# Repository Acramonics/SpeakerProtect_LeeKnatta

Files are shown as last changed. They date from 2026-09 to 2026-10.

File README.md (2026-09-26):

Speaker protect circuit from Lee Knatta
https://www.diyaudio.com/community/threads/improved-speaker-protection-circuit.302384/page-6

### PSU:

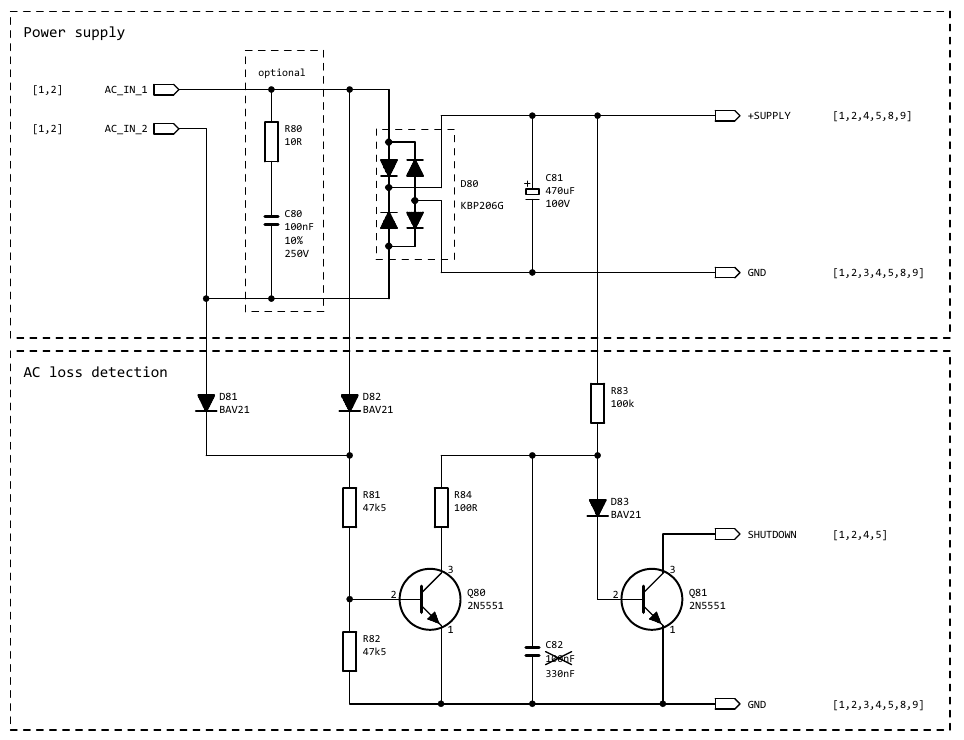
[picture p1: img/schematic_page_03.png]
PSU schematic


The power supply is just a full bridge rectifier with storage capacitor. The capacitor C81 should be large and able to withstand the voltage.
The AC loss detection uses half bridge rectifier D81 and D82 to make Q80 conduct and prevent C82 from charging up.
Once the AC fails, C82 charges through R83 and Q81 starts conducting. The "shutdown" is triggered by pulling low.

Assembly notes:
R82 is somewhat superfluous and could be left away with R81 = 100k instead. There are many such useless resistors in the design.
R84 aims to limit discharge current of C82 and may not be really necessary given that Q80 collector current is limited by the large value of R81.
R80 and C80 are optional and just a snubber for taming resonance of the transformer with the rectifier bridge. For now, I didn't install those components.

Debug:
Apply AC to the circuit and measure the supply voltage. Should be 1.4*Vac minus 1V4.
Also install (pull-up) resistor R1 (different schematic page) and measure the voltage at the "shutdown" terminal = supply voltage.
After removal of the AC, the voltage at the at the shutdown terminal should fall to 0V quickly while the supply voltage declines slowly.

### Startup Delay

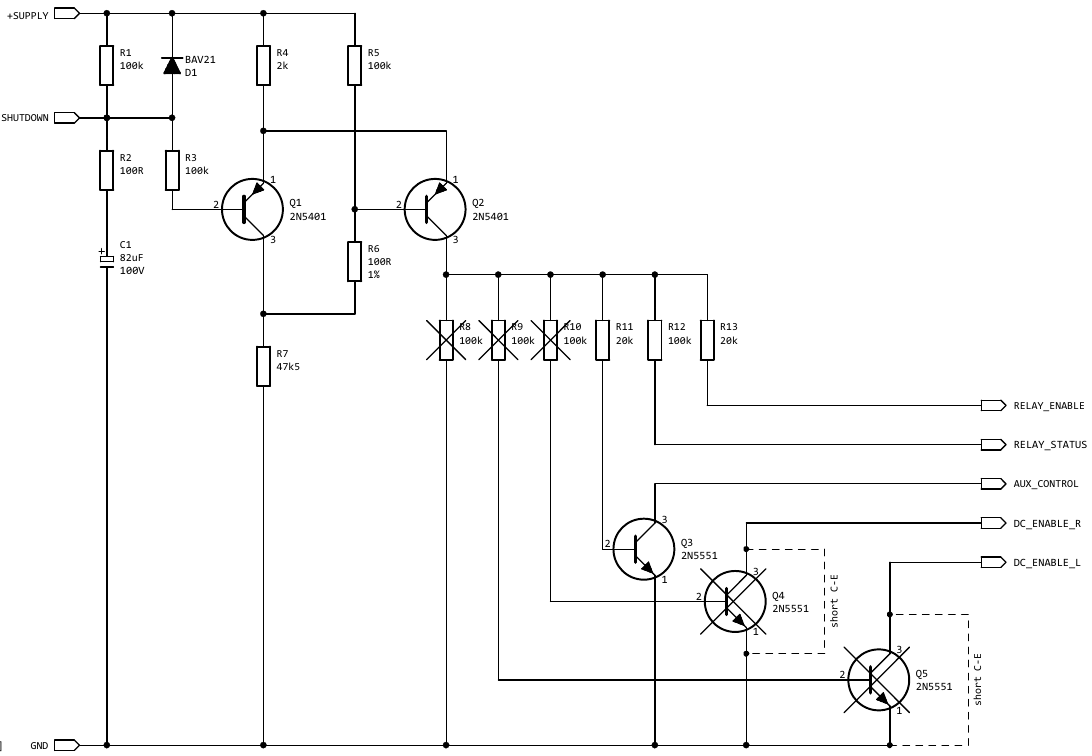
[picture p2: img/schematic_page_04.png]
Startup Delay


Resistor R1 charges capacitor C1 until the voltage is high enough for the Schmid trigger Q1 / Q2 to change state.
R2 is just for limiting discharge current in case the "shutdown" terminal is used by external switches / relays to avoid contact damage.
I revised the resistor values around the Schmid trigger to improve low voltage operation.

Notes:
Q4 and Q5 were added to enable DC detection only after the start-up so that DC events during start-up don't trigger the circuitry. This seemed a good idea with the "latch" mode operation enabled, but is a brain fart because once a DC event occurs, the DC detection circuitry is being disabled and may not be able to discharge C1 enough. Furthermore, if the DC error persists (blown output stage) the circuitry enters a hiccup mode, which is highly undesirable. Short Q4 and Q5 as illustrated.
I came to the conclusion that the "latch" mode is not such a great idea for typical applications. More on this on another page.

Debug:
The start-up delay is roughly 12 seconds with the component values shown.
After the delay, the voltage at the collector of Q2 goes high, enabling attached circuitry (if any).
On AC loss, the voltage should go low quickly.

### Status indication and latch

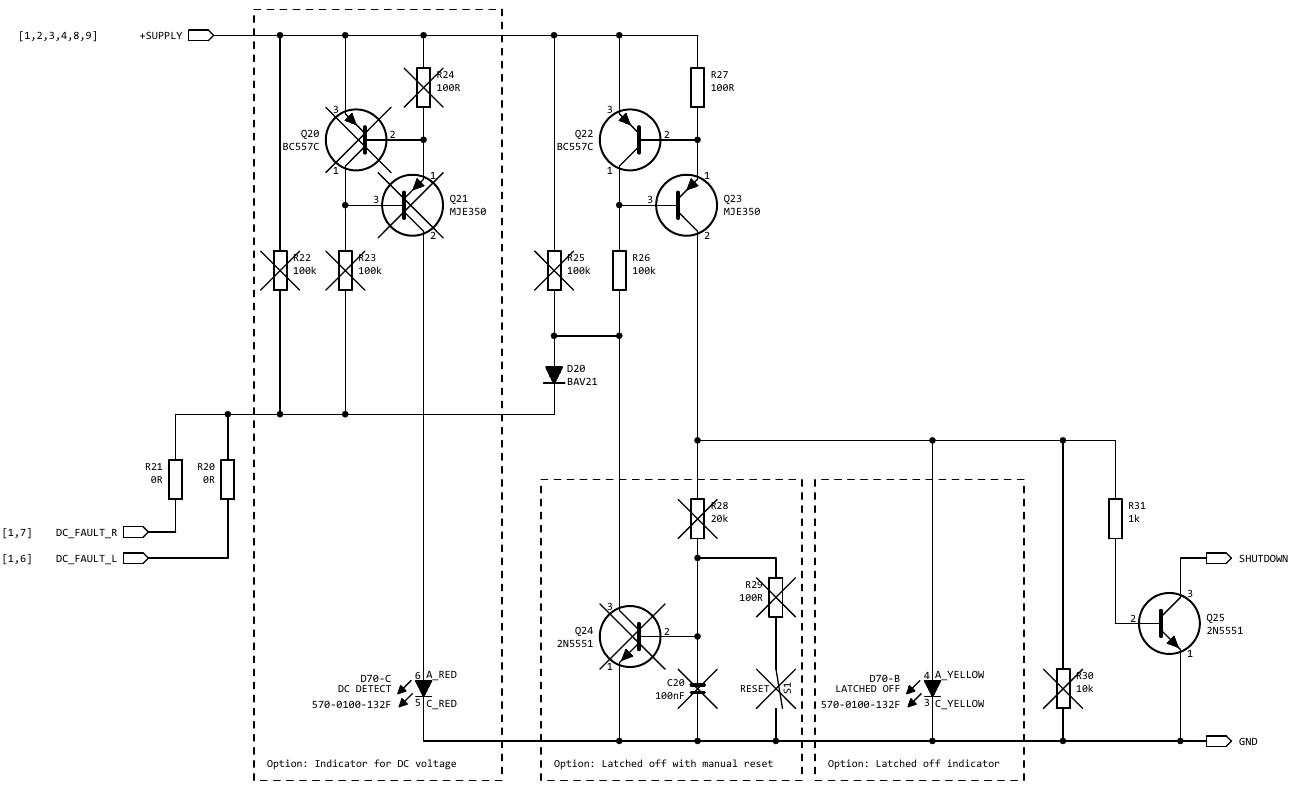
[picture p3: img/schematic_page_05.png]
Status and Latch


You may recognize that there are two current sources that can be switched on by pulling R23 / R26 low, thus enabling the reference voltage generation of the CCS.
The DC detection connects to the left through R20 and R21.
In case of a DC event, Q20 + Q21 output a few mA into the red LED that indicates that there is a DC error at the moment.
At the same time, Q22 and Q23 output a few mA into the yellow LED and if the components around Q24 are installed, the Q22 / Q23 CCS is kept on after C20 has charged up. The circuitry around Q24 is for the latch operation and keeps the Q22 / Q23 CCS on until switch S1 resets the latch.
The whole LED indicator and latch circuitry has been helpful in the past to debug the operation, but it is kind of impractical to manually reset the circuit in case a DC event has happened. On the other hand side, such events should be very rare. Without the latch enabled, the module re-connects the loudspeaker 12 seconds after the DC error has cleared. No issues with hiccup here. LED indicators are nice, but require a lot of components.

This time, I neither wanted any LED indicators, nor latch operation and just installed R20 + R21 and wired the cathode of D20 to the collector of Q25, bypassing all the circuitry on this page.

There are two options of LED indicators (if desired):
The traffic light thee color LED that makes most sense with the latch mode and a plain red / green LED.
For the R / G LED, the red one takes the place of the yellow one, thus the Q20 / Q21 circuitry should be left away.

3 LED colors:
Green = Loudspeaker connected, everything okay
Red = Acute DC error, loudspeaker disconnected
Yellow = Acute DC error and once red is off: DC error history, loudspeaker disconnected

2 LED colors:
Green = Loudspeaker connected, everything okay
Red = Either acute DC error or DC error history, loudspeaker disconnected

### DC Detection

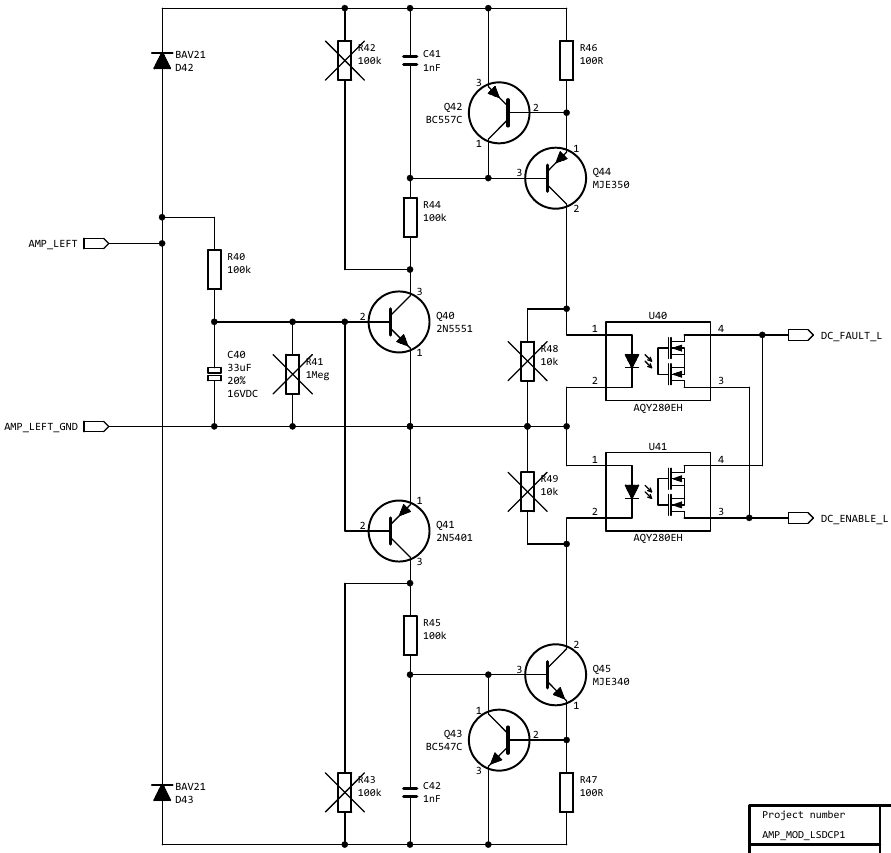
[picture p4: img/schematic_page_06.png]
DC Detection


Here is the DC detection of the left channel. The right channel is identical.

I reverted some connections back to the initial scheme, got rid of some useless components and optimized some component values.
Note that all crossed out components are superfluous and not installed.
I believe I explained the circuit earlier, but here we go again:

Q42 / Q44 and Q43 / Q45 are just current sources, which are switched on by Q40 / Q41 if the amplifier output (left side of the schematic) is DC long enough to charge C40 through R40.
C40 should be >33uF and <56uF. I installed 56uF.
I haven't completed AC tests, thus C41 / C42 are not optimized. A few nF / tens of nF may help to avoid false triggering on high frequency signals. If optimized, this bug may be a feature for oscillation detection maybe. Simulation shows that the detection is less sensitive to high frequencies with updated component values, thus maybe it even works well without C41 / C42.
The two CCS drive current through U40 and U41, which then activate the circuitry on the previous schematic page by pulling low the "DC_FAULT" node.

Galvanic isolation of U40 / U41 is great, but has a price (commercially). There is no need for low on resistance of the opto-couplers, which allows to pick cheaper ones.

DC detection threshold is roughly 3V3. This is good because it avoids false triggering on asymmetric signals (some music may be asymmetric) and this is bad because in case the amplifier has huge DC offset, the drivers may be damaged even at low voltage. There are more sensitive DC detection circuits in case this is a concern.

### Solid state relays

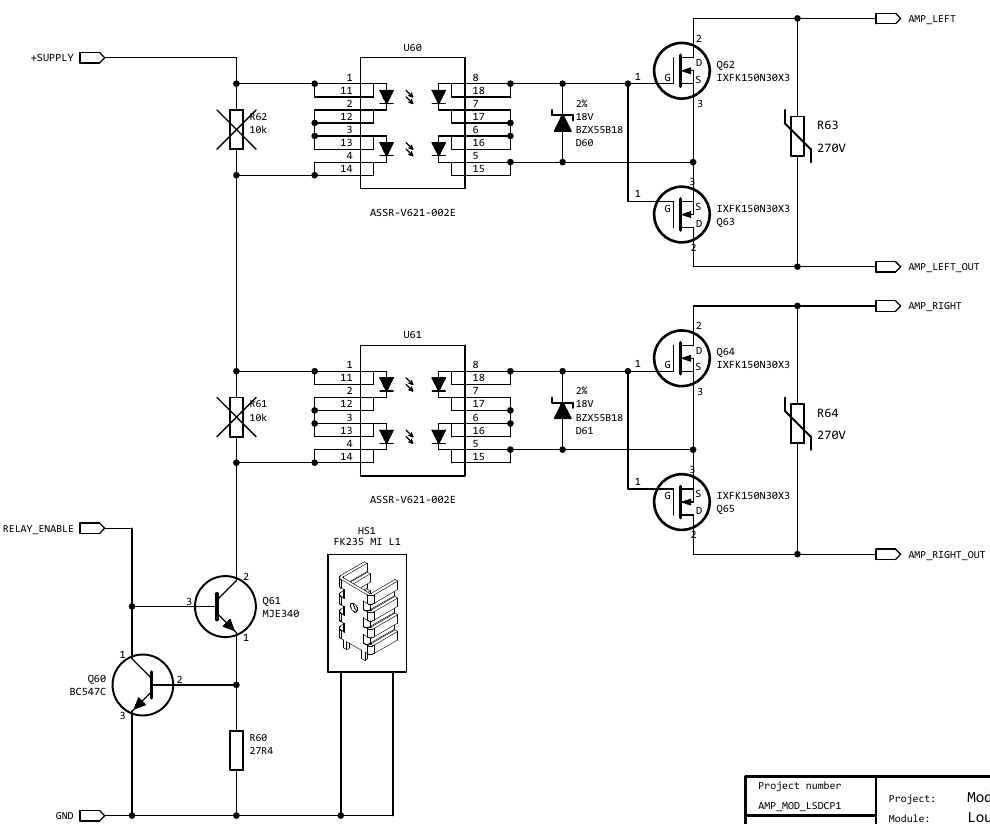
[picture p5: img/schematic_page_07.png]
Solid start relays


Now both photovoltaic drivers are controlled by the same current source Q60 / Q61.
The current source is switched on by the Schmid trigger.
Having the drivers in series also increases the minimum supply voltage required: The module works with >6VDC.
The output voltage of the photovoltaic drivers should be 13-14V roughly.

Power MOSFETs need to be chosen according to amplifier supply voltage / power and market situation.
Vds needs to be higher than the rail to rail power supply voltage. Lowest on resistance is desirable for lowest distortion.

The 18V Zeners protect the gates and the MOVs should be rated lower than the Vds of the MOSFET.

If the module is powered with >50V roughly, Q61 should have a small radiator.

Note the symbol for U60 / U61 is weird because I designed SMD / THT combo footprint and this is why there are 16 terminals.

# OK light

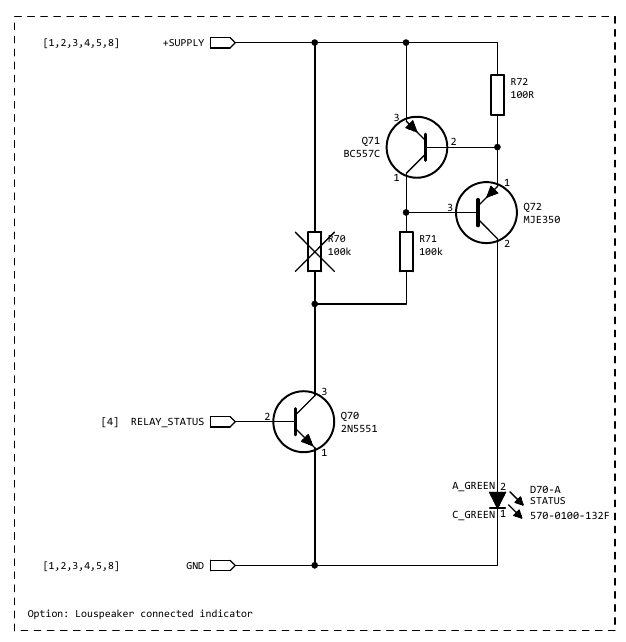
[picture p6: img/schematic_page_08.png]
OK light


This would be the optional green LED indicating that everything is okay:

Q70 switches on the CCS Q71 / Q72, which dumps a few mA through the green LED.
Nothing special.

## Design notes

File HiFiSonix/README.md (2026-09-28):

HiFiSonix

This is a different circuit from HiFi Sonix which uses the 
UPC1237 (Unisonic Taiwan, originally uPC1237 from NEC). These can be difficult to obtain.

https://www.hifisonix.com/projects/hifisonix-speaker-protection-board/

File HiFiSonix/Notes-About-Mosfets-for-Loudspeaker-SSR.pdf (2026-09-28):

# Hifisonix

# Notes about mosfets for Speaker Solid State Relays

Andrew C. Russell

July 2021

## www.hifisonix.com

19/09/2021 | www.hifisonix.com | 1

# Notes about using mosfets for loudspeaker solid state relays (1)

- Power mosfets come in 3 gate voltage thresholds: Logic, Intermediate (from some manufacturers) and standard level. Logic level devices are fully ON and meet stated Rds(on) specs with c. 2.5-3 volts applied to the gate wrt the source, and Standard level devices with 4.5-5 Volts (figures for 25 C – at higher temperatures, the gate threshold voltage drops – see the next slide)
- Logic level is preferable in all cases, but at higher drain-source voltage ratings, logic level devices are not readily available because the device gate oxide thickness (an important determinant of gate threshold voltage) has to be thicker to withstand the higher drain voltage, hence standard level devices only are available.
- Therefore, for amplifier voltages above 60V where logic level devices become scarce, you must use a standard level device but it must be low Rds(on) – say <5 milli-Ohms.
- This will ensure that with the 5-8 V supplied by the VOM127 or TLP191 gate drivers, the Rds(on) of the individual mosfets will be below 10 milli-Ohms, which is still 20% to 50% lower than a good high powered relay when new. Electro-mechanical relay contact resistance degrades over time, and especially so when switching a load. This is not the case with mosfet SSR.
- The peak drain current should be rated for the worst case expected short circuit current. For most amplifiers incorporating short circuit protection, this will be with a in the region of 2 Ohms
- Never use a mosfet beyond its absolute maximum ratings – if for example the amplifier supply voltage is likely to occasionally be as high as 65V, use the next available voltage group which will be 75V

## Typical Gate Threshold Voltages for Power Trench mosfets

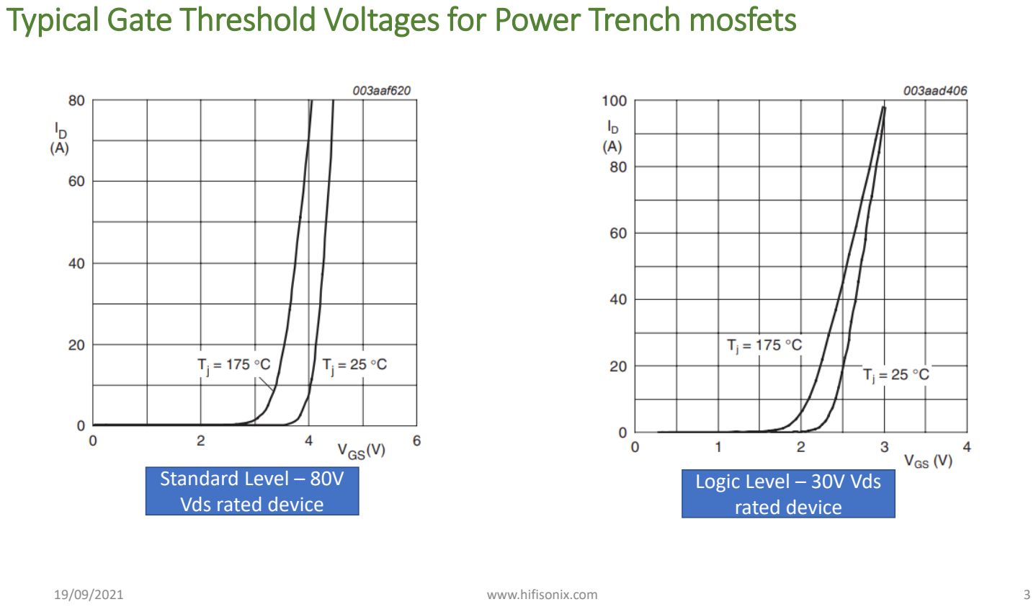
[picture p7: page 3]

Standard Level – 80V
Vds rated device

Logic Level – 30V Vds
rated device

## Notes about using mosfets for loudspeaker solid state relays (cont.)

- For the most part, the SSR mosfets will deal with single switching events at medium to low powers - Under worst case fault conditions, as for example when an amplifier output device fail short to either of the supply rails, the SSR may be called upon to momentarily conduct and then switch currents of 10~15A on a large amplifier - In the case of an amplifier output short to ground, this figure can be 5~10x higher if the amplifier does not incorporate current limiting. Since most amplifiers incorporate some sort of current limiting and fusing, these kinds

of current levels are unusual in practice.

## - Mosfet based SSR’s can be used in amplifiers that do not incorporate current limiting, but special techniques must then be used to speed-up the switching time to < 100us. The 2~5ms using standard photovoltaic drivers is usually not quick enough to protect the amplifier output devices. You can

see an amplifier that uses this technique here (https://www.ovationhifidelity.com/product/model-1721/)

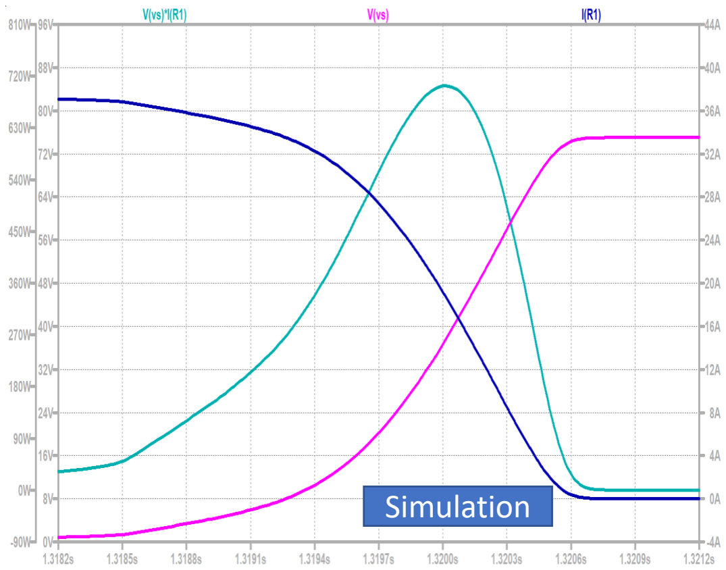
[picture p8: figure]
Simulation

The simulation on the right shows the peak currents likely to be encountered momentarily in a scenario where the amplifier output at the speaker terminals is shorted out – generally a worst case situation.

The rise/fall time of the driving source was set to 2ms to simulate the worst case mosfet gate drive using a standard photovoltaic driver like a VOM127 or TLP191.

In this example, an amplifier powered off ±75V rails and assuming no rail droop (highly unlikely in practice under this type of fault condition) peak currents in the region of 75A can be expected, leading to peak one shot mosfet dissipation of 720 Watts.

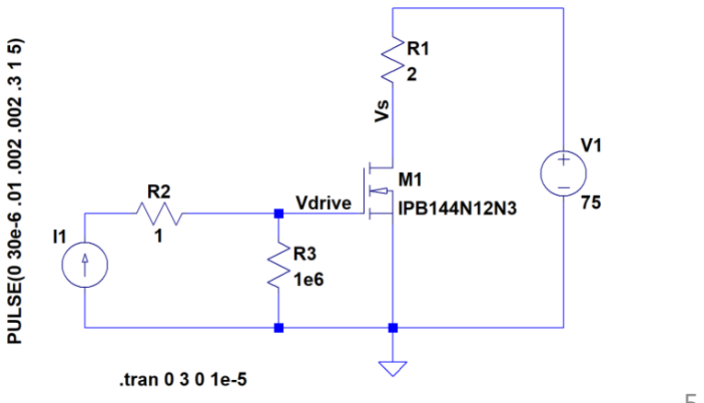
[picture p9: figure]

Note that high power is dissipated only during the switching event. When fully ON, little power is dissipated because the mosfet Rds(on) is only a few milli-Ohms. For a single shot event, the average power computed over 1 second is therefore very low and in this example only about 2.5W assuming a single switch off event.

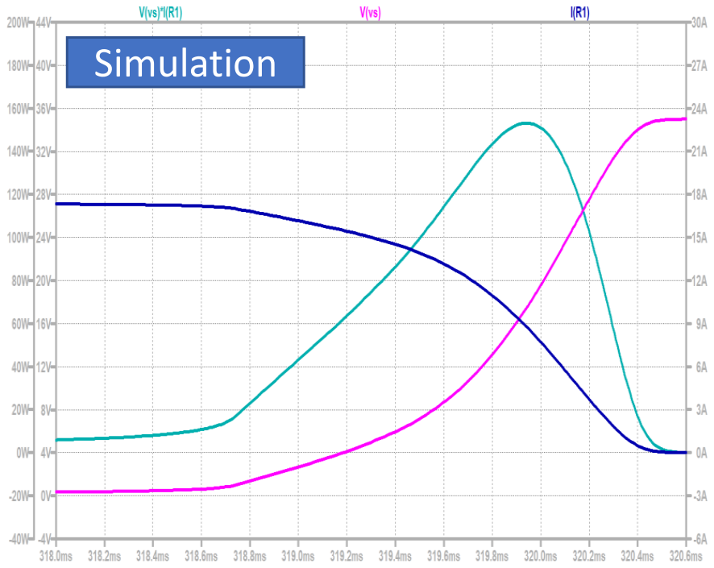
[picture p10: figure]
Simulation

In this example, the supply rail is 35V, and the switched speaker load 2 Ohms. The peak switching power encountered by the mosfet in the region of 160W (the same low Rds(on) mosfet was used for this simulation).

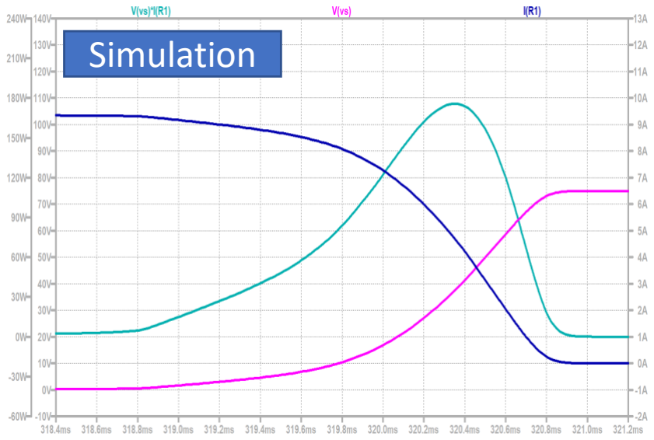
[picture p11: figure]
Simulation

In this example, the supply rail is 75V and the speaker load 8 Ohms. The peak switching power encountered by the mosfet in the region of 180W. The average single shot power computed over 1 second is < 0.25W (the same low Rds(on) mosfet was used for this simulation).

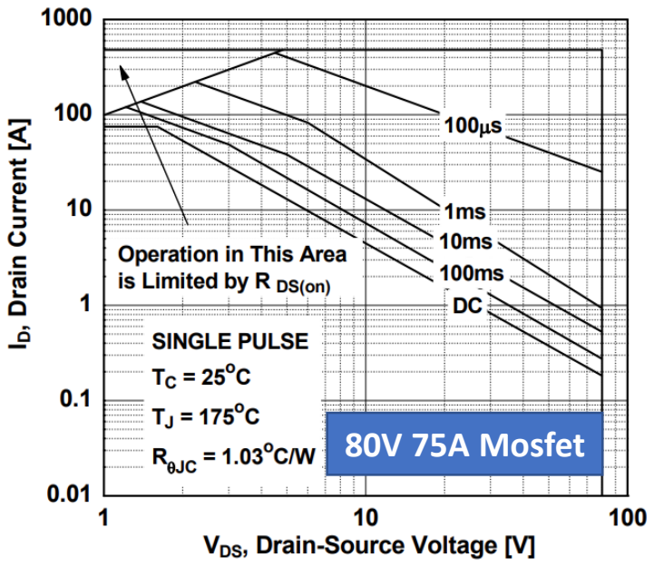
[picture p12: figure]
80V 75A Mosfet

The graph on the right is typical of a power mosfet designed for high power switching applications, in this case an 80V device rated at 75 Amps with an Rds(on) of 5.3milli Ohms. These types of ‘switching’ mosfets have poor SOA when operated in the linear or DC mode.

To reduce power dissipation and remain within the SOA, the devices must switch quickly, or the peak current flowing through them must be limited to safe levels.

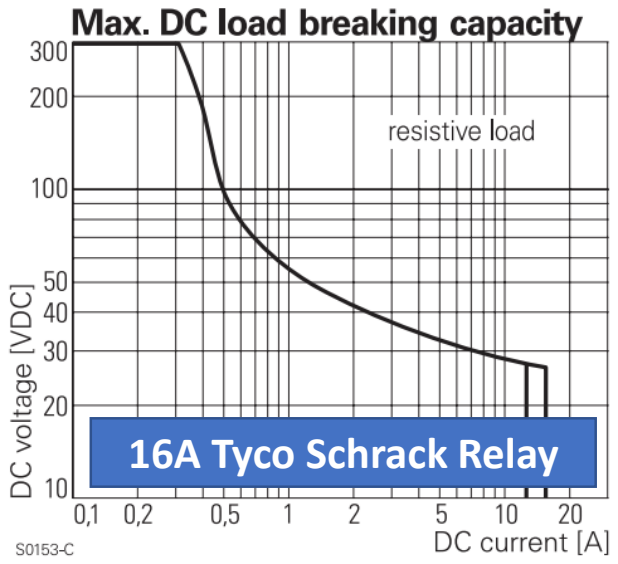
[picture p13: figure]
16A Tyco Schrack Relay

The graph on the right is for a good quality Tyco Schrack 16A industrial grade relay. The relay SOA is better than the mosfet used above, but there is a hard stop at 16A. Currents above this figure will damage the contacts, leading to a drop in current handling capability and early failure during some future switching event. The mosfets in contrast will easily switch 100A provided it is done quickly to minimize the peak power dissipation during the switching event. Further, the mosfet switches do not wear out.

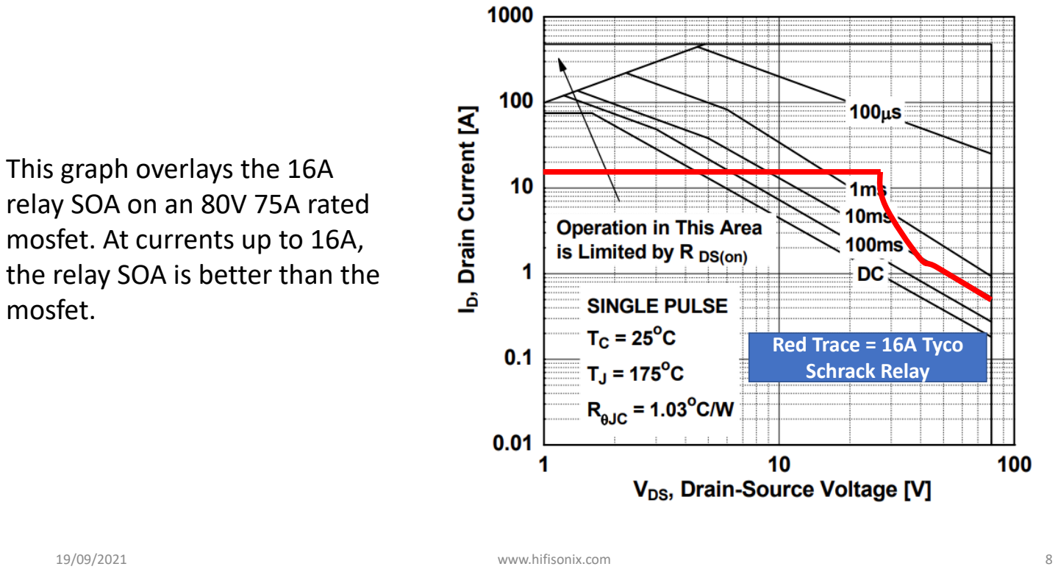
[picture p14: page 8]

## This graph overlays the 16A relay SOA on an 80V 75A rated

mosfet. At currents up to 16A,

## the relay SOA is better than the

mosfet.
Red Trace = 16A Tyco
Schrack Relay

# Using the Current Overload Detection Input (terminal U6) – Some Ideas

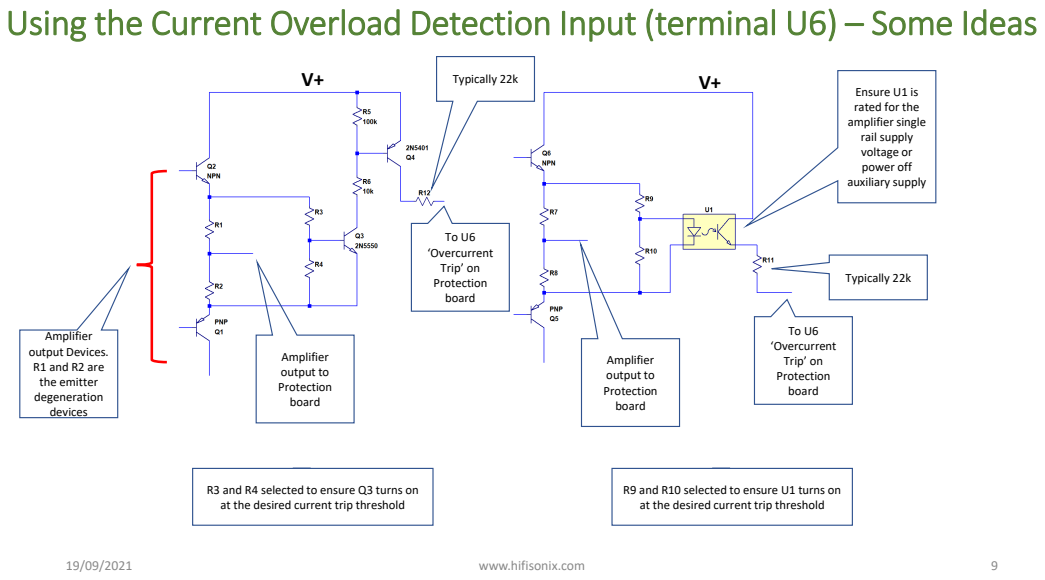
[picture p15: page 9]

R3 and R4 selected to ensure Q3 turns on
at the desired current trip threshold

R9 and R10 selected to ensure U1 turns on

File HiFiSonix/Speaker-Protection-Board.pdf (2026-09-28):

# Hifisonix

# Speaker Protection Board

Andrew C. Russell

July 2021 (updated April 2023 with slide 9)

## www.hifisonix.com

Important: This project is strictly for DIY/personal use only. If you wish to use this design, or aspects of this design, for commercial applications and/or resale, kindly contact me via

## the hifisonix website or at bonsai(at)hifisonix.com

Click here for Double sided, silk screened PCB’s for the speaker Protection Board (http://hifisonix.com/hifisonix-standard-psu/)

## This project uses all through hole components

19/09/2021 | www.hifisonix.com | 1

# Specifications – Hifisonix Speaker Protection board

Protection IC: Unisonic UPA1237 (http://www.unisonic.com.tw/datasheet/UPC1237.pdf)
Protection functions: Switch on mute, switch off mute, DC offset protection; overcurrent trip input facility
DC Offset detect speaker disengage time: < 20ms for Vdc = 50V; 100ms for Vdc = 10V; 3~5 seconds for Vdc = 2V Current Overload disengage time: ~5ms
Usable Supply Voltage: 25 to 75V (requires resistor changes - see table on slide 6)
Options: latching/non-latching operation by means of link
Speaker Relay: TO-220 high power mosfets configured as bi-directional solid state relay
ON resistance: dependent upon mosfets used (see Table 1) but typically <20 milli-Ohms and as low as 3 milli-Ohms
Application: Can be used with single supply or slit supply rail amplifiers
PCB Dimensions: 80mm x 50mm

Attention: the values shown in the circuit diagram on slide 4 are for amplifier +ve supply voltages of > 45V. For other supply voltages, see slide 6

# Brief Description

This speaker protection board uses the popular UPC1237 IC to provide DC offset protection, AC power detection, DC detection and overcurrent protection (see notes later in this document), facilitating comprehensive speaker protection with just a few extra components
The original µPC1237 (http://hifisonix.com/wordpress/wp-content/uploads/2021/09/NEC-uPC1237.pdf) was created by NEC Japan, but discontinued many years ago. Taiwanese semiconductor company Unisonic now supply a pin for pin replacement, the UPC1237 (http://hifisonix.com/wordpress/wp-content/uploads/2021/09/UPC1237.pdf) available from numerous suppliers in the US and Europe (UK builders can get them from Cricklewood Electronics in London via their website).
There are a lot of low cost speaker protection boards based on the UPC1237 available on eBay and AliExpress. Most use cheap relays to connect the amplifier to the speakers and will fail if there is a catastrophic DC offset, as is the case if one of the output devices on the amplifier go short – see this thread on diyAudio for example (https://www.diyaudio.com/forums/solid-state/191449-output-relays.html) – or if the amplifier output is shorted to 0V. The relays used by the complainant in this case were industrial grade Tyco 16A devices in which the contacts welded short, putting 75V DC onto the B&W 703 bass loudspeakers on one of the channels, cooking them in about 3 seconds. The repair bill was close to US$400.
Relays are a VERY BAD solution when dealing with high voltage, high current switching, or with inductive loads. Instead of using relays between the amplifier output and the speaker, the hifisonix speaker protection board uses power mosfets. These offer lower on resistances than relays, easily switch 10x the currents a good quality relay can, suffer no contact degradation over time, handle inductive loads and switch DC just as well as AC.
The standard UPC1237 device will work to 60V. On the hifisonix board, a simple zener voltage limiter extends the maximum operating voltage allowing use with high power amplifiers with supply voltages of up to +-75V (using suitable mosfets of course – see table later in this document)

## Hifisonix Speaker Protection Board Schematic

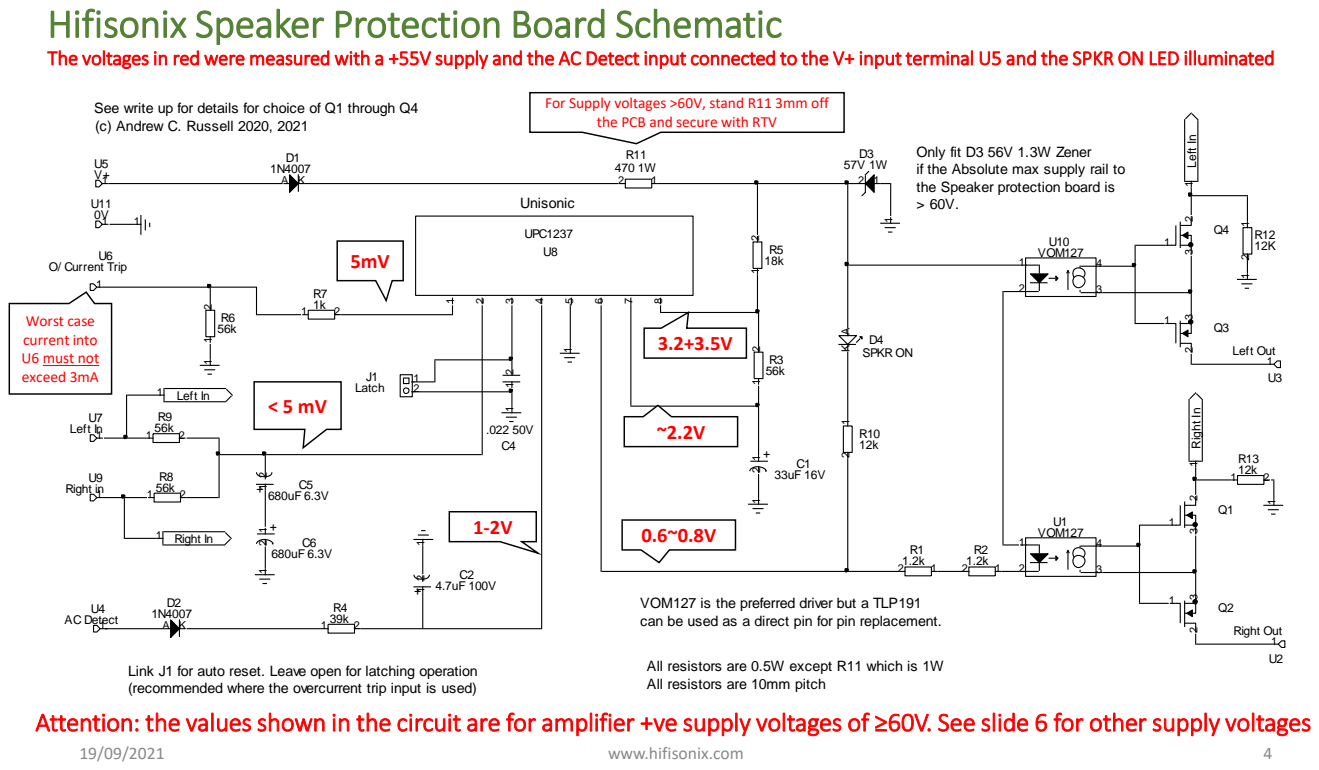
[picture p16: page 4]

The voltages in red were measured with a +55V supply and the AC Detect input connected to the V+ input terminal U5 and the SPKR ON LED illuminated

For Supply voltages >60V, stand R11 3mm off

See write up for details for choice of Q1 through Q4
(c) Andrew C. Russell 2020, 2021

the PCB and secure with RTV

Only fit D3 56V 1.3W Zener
if the Absolute max supply rail to
the Speaker protection board is

VOM127 is the preferred driver but a TLP191
can be used as a direct pin for pin replacement.

All resistors are 0.5W except R11 which is 1W
All resistors are 10mm pitch

Link J1 for auto reset. Leave open for latching operation
(recommended where the overcurrent trip input is used)

Attention: the values shown in the circuit are for amplifier +ve supply voltages of ≥60V. See slide 6 for other supply voltages

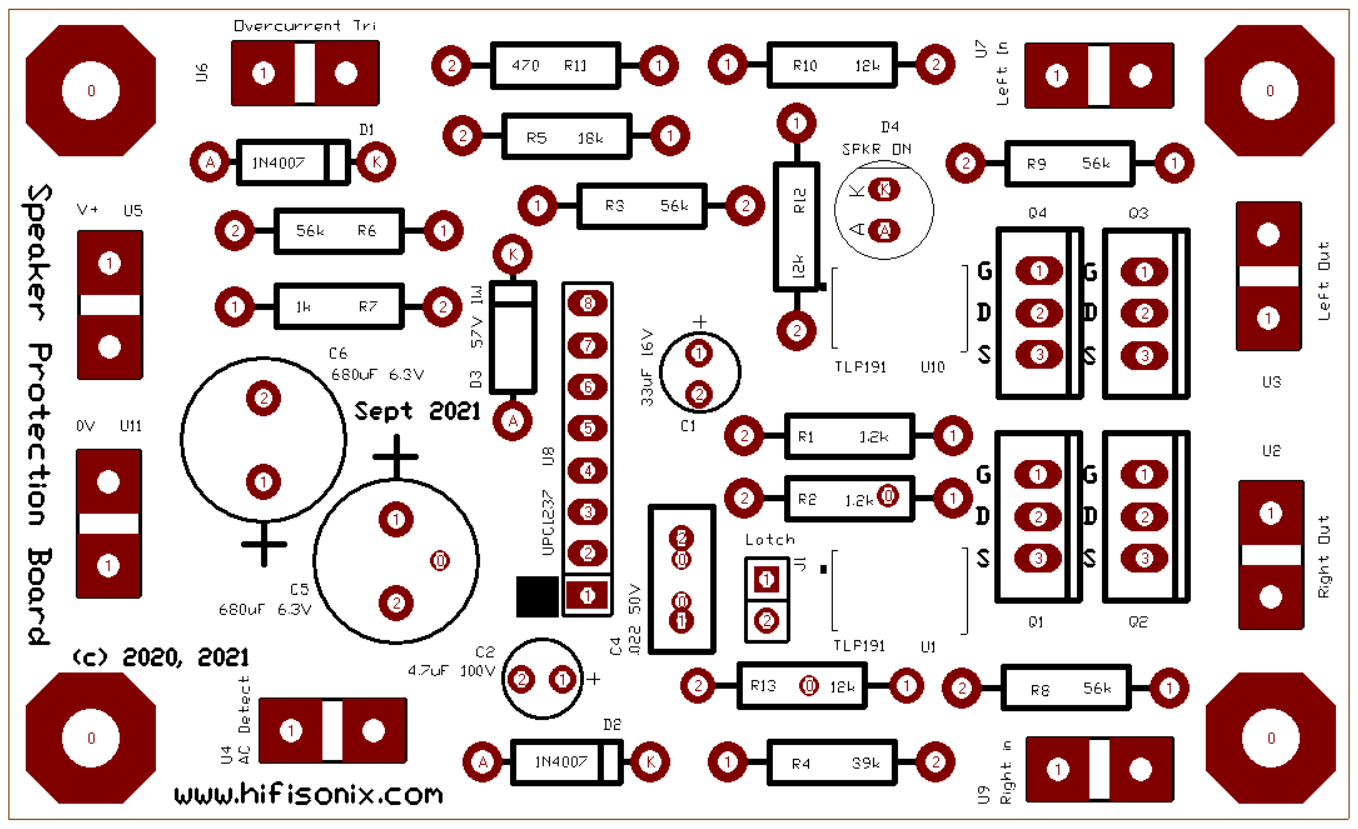
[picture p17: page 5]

# Resistor values for selected supply voltages – 20V to 75V

Vs is the
supply
voltage at
connector U5
Vs | R1 | R2 | R4 | R5 | R10
20 | 270 | 330 | 12k | 8.2k | 3900
25 | 330 | 330 | 15k | 8.2k | 4700
30 | 390 | 390 | 18k | 10k | 5600
35 | 560 | 560 | 22k | 10k | 6800
40 | 680 | 680 | 27k | 12k | 6800
45 | 820 | 820 | 27k | 15k | 8200
50 | 1k | 1k | 33k | 15k | 10k
55 | 1k | 1k | 33k | 18k | 10k
60 | 1.2k | 1.2k | 39k | 18k | 12k
65 | 1.2k | 1.2k | 39k | 18k | 12k
70 | 1.5k | 1.5k | 39k | 18k | 12k
75 | 1.5k | 1.5k | 39k | 18k | 15k

Note: Above 57V, a simple zener regulator (D3) limits the supply voltage to 57V. See the circuit diagram for details.

Table 1 – Mosfet Selection. Note: All mosfet types are TO-220.

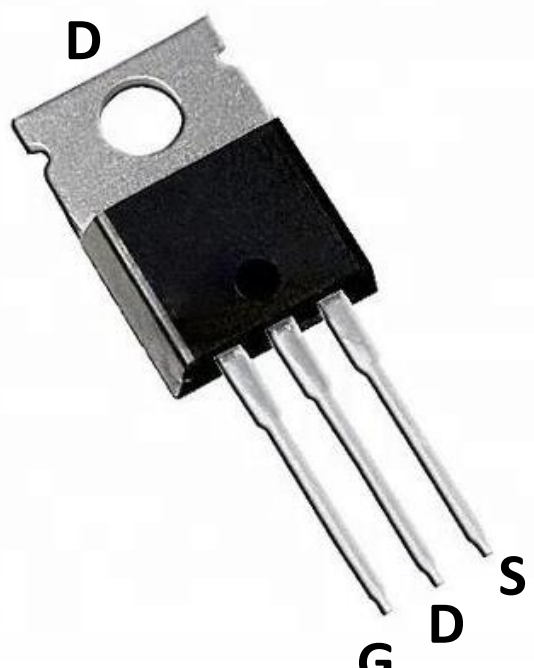
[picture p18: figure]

Amplifier Absolute Max Supply Voltage | Suggested Mosfets
<= +-30V | IRLB8748PBF, (https://www.mouser.co.uk/ProductDetail/Infineon-IR/IRLB8748PBF?qs=9%252BKlkBgLFf3gv5ktjzjOKQ%3D%3D) IPP042N03L G, (https://www.mouser.co.uk/ProductDetail/Infineon-Technologies/IPP042N03L-G?qs=mzcOS1kGbgcoiRIwFnG3QQ%3D%3D) PSMN2R7-30PL,127, (https://www.mouser.co.uk/ProductDetail/Nexperia/PSMN2R7-30PL127?qs=5eMHoInnifTRbFSqVX3huA%3D%3D) IRLB8743PBF, (https://www.mouser.co.uk/ProductDetail/Infineon-IR/IRLB8743PBF?qs=9%252BKlkBgLFf0rfIKznQZ2TQ%3D%3D) STP200N3LL (https://www.mouser.co.uk/ProductDetail/STMicroelectronics/STP200N3LL?qs=aVyJF2WnouSFHSocQsazaw%3D%3D)
+-40V | PSMN2R1-40PL, (https://www.mouser.co.uk/ProductDetail/Nexperia/PSMN2R1-40PLQ) PSMN1R9-40PL, (https://www.mouser.co.uk/ProductDetail/Nexperia/PSMN1R9-40PLQ) IRF40B207, (https://www.mouser.co.uk/ProductDetail/Infineon-IR/IRF40B207?qs=E2FFEhwHWtcQOIdwe%2FkgSA%3D%3D) TK3R1A04PL,S4X, (https://www.mouser.co.uk/ProductDetail/Toshiba/TK3R1A04PLS4X?qs=bUPhaerQQeFu1IQ0dTaruQ%3D%3D) IPA041N04NGXKSA1, (https://www.mouser.co.uk/ProductDetail/Infineon-Technologies/IPA041N04NGXKSA1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) PSMN8R0-40PS,127, (https://www.mouser.co.uk/ProductDetail/Nexperia/PSMN8R0-40PS127?qs=HnaUIVfgVjDfYMvAYWPknw%3D%3D) IPP80N04S404AKSA1, (https://www.mouser.co.uk/ProductDetail/Infineon-Technologies/IPP80N04S404AKSA1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) PSMN4R5-40PS,127 (https://www.mouser.co.uk/ProductDetail/Nexperia/PSMN4R5-40PS127?qs=HnaUIVfgVjAfpq7ccKTONA%3D%3D)
+-50V ~ +-60V | BUK954R8-60E, (https://www.mouser.co.uk/ProductDetail/Nexperia/BUK954R8-60E127) PSMN2R5-60PL, (https://www.mouser.co.uk/ProductDetail/Nexperia/PSMN2R5-60PLQ?qs=l4PUViidnEyrgIa1%252BNJIgQ%3D%3D) PSMN3R3-60PLQ, (https://www.mouser.co.uk/ProductDetail/Nexperia/PSMN3R3-60PLQ) PSMN4R2-60PL, (https://www.mouser.co.uk/ProductDetail/Nexperia/PSMN4R2-60PLQ) IXTP120N075T2, (https://www.mouser.co.uk/ProductDetail/IXYS/IXTP120N075T2?qs=cvHLLyFtoE0X8skFVkxRAw%3D%3D) STP220N6F7 (https://www.mouser.co.uk/ProductDetail/STMicroelectronics/STP220N6F7?qs=XtgyILOJlWPqoIRfxQFssA%3D%3D)
>+-60V ~ +-75V | PSMN3R5-80PS, (https://www.mouser.co.uk/ProductDetail/Nexperia/PSMN3R5-80PS127) PSMN4R4-80PS, (https://www.mouser.co.uk/ProductDetail/Nexperia/PSMN4R4-80PS127?qs=HnaUIVfgVjDMaHOXqkOtQQ%3D%3D) PSMN4R3-80PS, (https://www.mouser.co.uk/ProductDetail/Nexperia/PSMN4R3-80PS127) FDP4D5N10C, (https://www.mouser.co.uk/ProductDetail/onsemi/FDP4D5N10C?qs=F5EMLAvA7IAO92U50NP5Zw%3D%3D) TK5R3E08QM,S1X, (https://www.mouser.co.uk/ProductDetail/Toshiba/TK5R3E08QMS1X?qs=4qgZ1GHix0Xps7XRMmtJSQ%3D%3D) FDP053N08B-F102, (https://www.mouser.co.uk/ProductDetail/onsemi-Fairchild/FDP053N08B-F102?qs=0lQeLiL1qybSLhtd9pZp4A%3D%3D) IRF1407PBF, (https://www.mouser.co.uk/ProductDetail/Infineon-IR/IRF1407PBF?qs=2r01AXMCG3MFomct0c3JxA%3D%3D) DMTH10H005LCT, (https://www.mouser.co.uk/ProductDetail/Diodes-Incorporated/DMTH10H005LCT?qs=5666Nh5RPmYDiApfkPHvLg%3D%3D) SQP120N10-09_GE3, (https://www.mouser.co.uk/ProductDetail/Vishay-Siliconix/SQP120N10-09_GE3?qs=Nn1VXUNwu%252B%2Fdh2XamFxneg%3D%3D) PSMN3R3-80PS,127 (https://www.mouser.co.uk/ProductDetail/Nexperia/PSMN3R3-80PS127?qs=s4XK1XdnRimV2ZXQsJW%252BHg%3D%3D)

The table above is a list of indicative power mosfets that can be used with the speaker protection board. In general, logic level types with lower gate charge (‘Qdg’) are preferred.

G

## Device Pinout

## How to wire in the Protection Board to your Amp

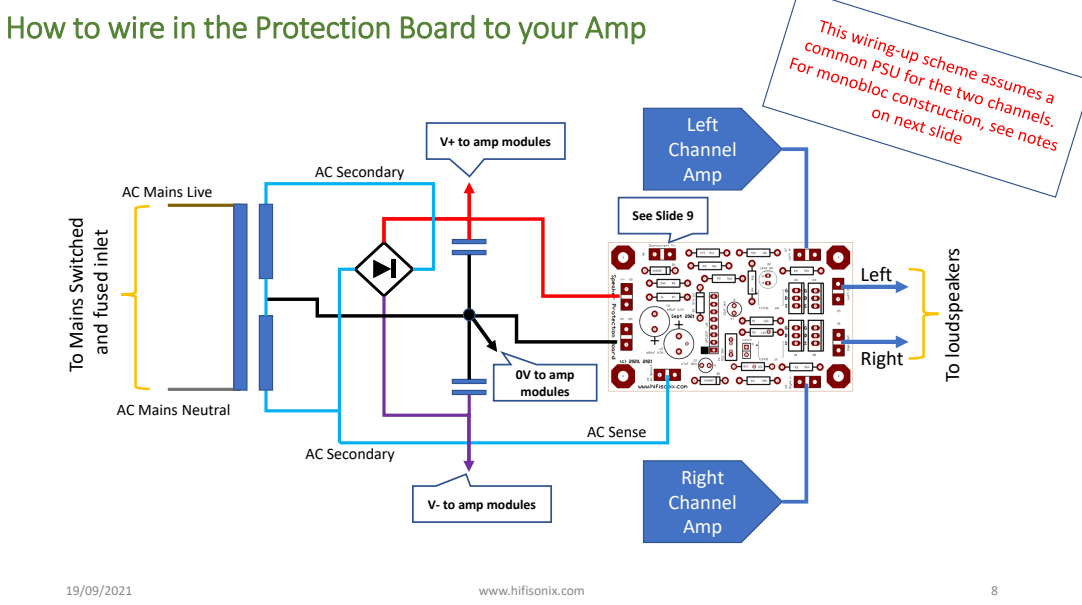
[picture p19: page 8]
Left Channel Amp; Right Channel Amp; To loudspeakers; Left; Right; AC Sense; 0V to amp modules; See Slide 9; AC Secondary

V+ to amp modules

AC Mains Live

To Mains Switched

and fused inlet

AC Mains Neutral

V- to amp modules

## How to Wire the Protection Board AC Sense with Split Separately Rectified and Smoothed Secondaries

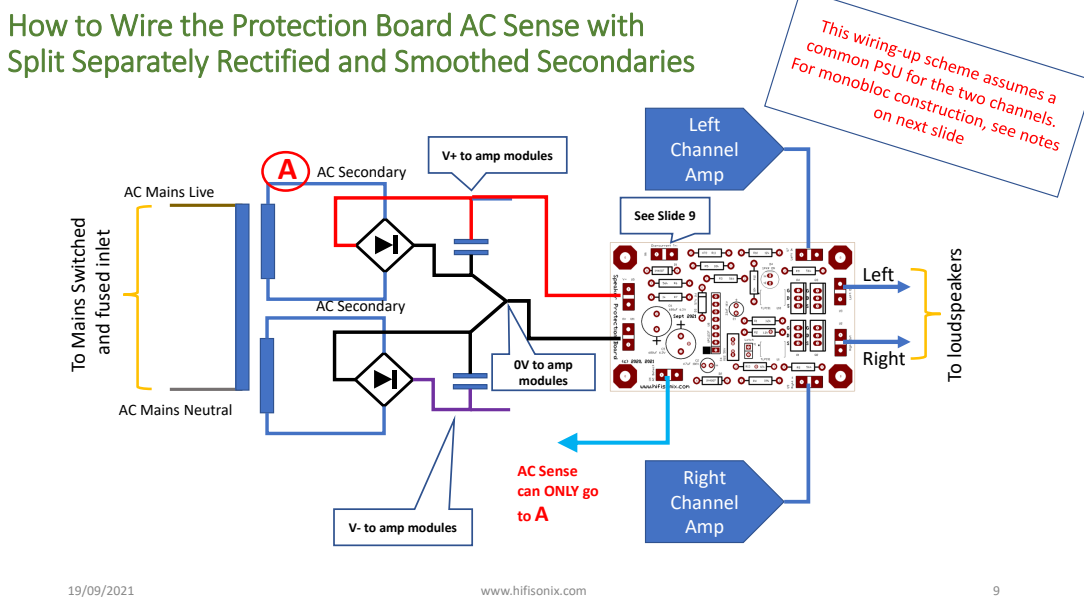
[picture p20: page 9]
Left Channel Amp; Right Channel Amp; To loudspeakers; Left; Right; 0V to amp modules; See Slide 9; AC Secondary

V+ to amp modules

AC Mains Live

To Mains Switched

and fused inlet

AC Mains Neutral

AC Sense
can ONLY go

V- to amp modules

## What if my amp uses separate power supplies for each channel?

- You only need one AC detect signal, so its ok to take it off just one of the secondaries. All the protector board is doing is looking to see if AC is present - it gives a long speaker switch-on delay

### when AC is applied but a quick one when the AC is removed. This AC detection is used to

prevent speaker ON/OFF thumps when you power your amp up or down.

- If you are using separate +- supplies for each amplifier (i.e. monobloc construction) you can also just take the +- supply to the protection board off 1 amplifier power supply provided the two amplifiers share the same 0V. This will typically be the case if the amplifier 0 Volts are connected to the chassis for safety, or, if the input signal grounds are joined together at the input socket and the amplifier main 0V goes to the chassis via a ground lifter.
- If the two amplifier channels 0V's are not joined in any way, you will need to use a separate

### Speaker Protection board for each channel

## Using the Current Overload Detection Input (terminal U6)

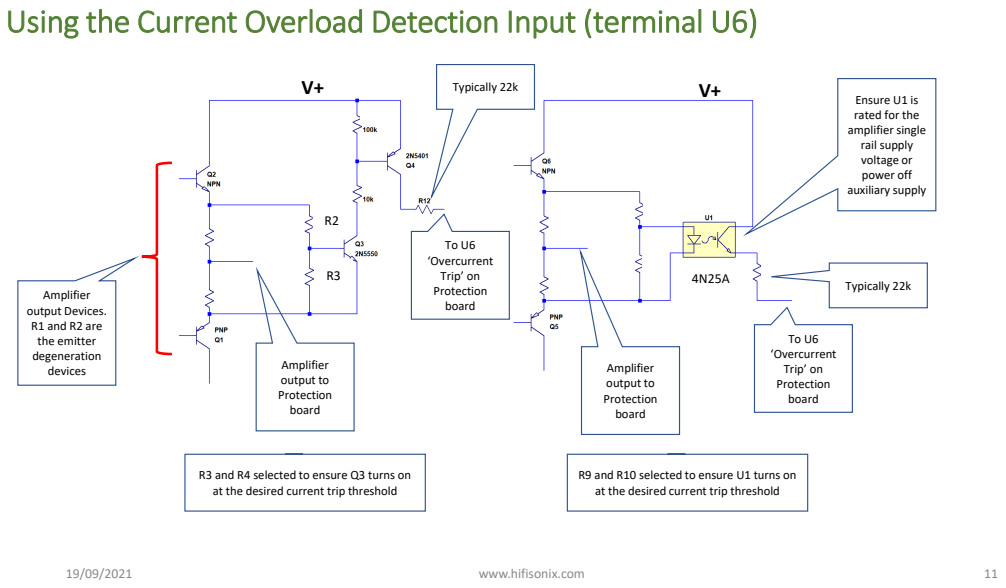
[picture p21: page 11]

R3 and R4 selected to ensure Q3 turns on
at the desired current trip threshold

R9 and R10 selected to ensure U1 turns on

# Overcurrent Protection with multiple output pairs

You can approach the current limiting in either of these two ways:-

1. Set the trip current for one pair. The total load current will then be the trip current on the sensing pair multiplied by the number of output pairs. Example: assume a 6 pair amplifier. Set the overcurrent trip for the sensing pair at 7A then the total output current of the amplifier before tripping will be 6 x 7 or 42A
2. The other method is to set the max allowable current for a given configuration, and then calculate the current trip setting resistors for the total output current. Example: assume a 6 pair amplifier where you want to set the max total output current for 30A. Each pair will then conduct 5A and the current trip resistor values selected accordingly.

I do not recommend using an output transistor pair much above 7A. If you want more output current, add more output pairs. See Robert Cordell ‘Designing Audio Power Amplifiers’ (2011 Edition) page 290 fig. 14.8

It is strongly recommended that the Speaker Protection Board is set to ‘Latching’ operation if you are using the overcurrent detect feature. To enable Latching functionality, leave J1 OPEN. If the Speaker Protection Board trips on overcurrent detect, you will have to power the amplifier completely down to reset it

# Transistor overcurrent sensing circuit (simulation)

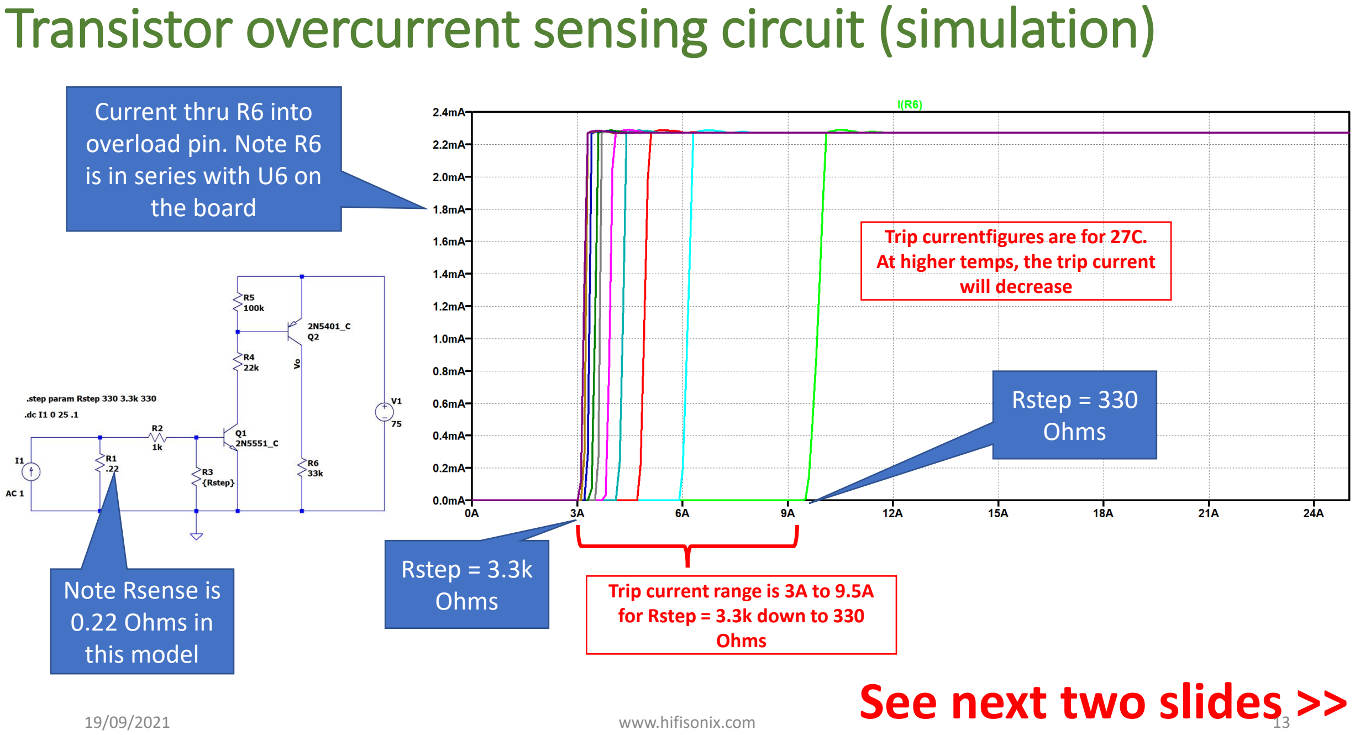
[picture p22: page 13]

Rstep = 330
Ohms

Rstep = 3.3k
Ohms | Trip current range is 3A to 9.5A for Rstep = 3.3k down to 330 Ohms

Trip currentfigures are for 27C. At higher temps, the trip current will decrease

Current thru R6 into
overload pin. Note R6
is in series with U6 on
the board

Note Rsense is
0.22 Ohms in
this model

# See next two slides >>

As already mentioned, it is not recommended you use combinations in the pink coloured area which is > 7.3A per output transistor pair.

### 1. Select your emitter degeneration

resistor value column

### 2. Select the peak current output you

want per output pair – limit it to the white area in the table

### 3. Look on the left hand side column

to ascertain the value of R3 (this is the lower leg of the sense transistor base voltage divider). R2 is always 1k per the previous slide.

R3 | 0.1 | 0.12 | 0.15 | 0.18 | 0.22 | 0.27 | 0.33 | 0.39 | 0.47
180 | 35 | 29 | 23 | 19.1 | 15.8 | 12.7 | 10.4 | 8.7 | 7.3
220 | 29 | 24.2 | 19.5 | 16.2 | 13 | 10.8 | 8.8 | 7.5 | 5.9
270 | 24.5 | 20.8 | 16.5 | 13.8 | 11.1 | 9 | 7.4 | 6.4 | 5.2
330 | 20.1 | 17.7 | 14.2 | 11.7 | 9.6 | 7.8 | 6.4 | 5.4 | 4.5
390 | 18.6 | 15.5 | 12.6 | 10.4 | 8.5 | 7 | 5.6 | 4.7 | 4
470 | 16.3 | 13.7 | 11 | 9 | 7.3 | 6.1 | 5 | 4.3 | 3.5
560 | 14.5 | 12.2 | 9.8 | 8.1 | 5.9 | 5.3 | 4.4 | 3.7 | 3
680 | 12.8 | 10.8 | 8.7 | 7.2 | 5.2 | 4.8 | 3.9 | 3.4 | 2.8
820 | 11.5 | 9.6 | 7.8 | 6.5 | 4.7 | 4.3 | 3.5 | 3 | 2.4
1k | 10.3 | 8.8 | 7 | 5.8 | 4.4 | 3.8 | 3.2 | 2.6 | 2.2
1.2k | 9.2 | 8 | 5.9 | 5.4 | 4 | 3.4 | 2.9 | 2.6 | 2
1.5k | 8.4 | 7.3 | 5.3 | 4.8 | 3.7 | 3 | 2.6 | 2.3 | 1.8
1.8k | 8.1 | 6.8 | 5.4 | 4.5 | 3.4 | 2.8 | 2.5 | 2.1 | 1.5
2.2k | 7.5 | 6.3 | 5.1 | 4.2 | 3 | 2.6 | 2.4 | 1.9 | 1.6
5.6k | 6.1 | 5 | 4.2 | 3.3 | 2.7 | 2.2 | 1.8 | 1.7 | 1.2

### Output stage emitter degeneration resistor value

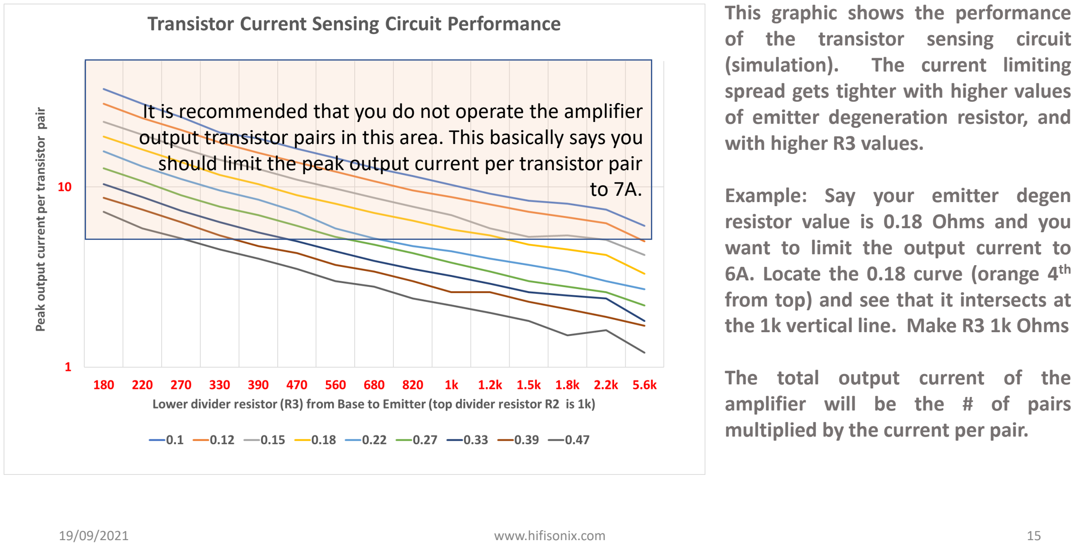
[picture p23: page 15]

It is recommended that you do not operate the amplifier output transistor pairs in this area. This basically says you should limit the peak output current per transistor pair to 7A.

This graphic shows the performance of the transistor sensing circuit (simulation). The current limiting spread gets tighter with higher values of emitter degeneration resistor, and with higher R3 values.

Example: Say your emitter degen resistor value is 0.18 Ohms and you want to limit the output current to 6A. Locate the 0.18 curve (orange 4

| th
from top) and see that it intersects at the 1k vertical line. Make R3 1k Ohms

The total output current of the amplifier will be the # of pairs multiplied by the current per pair.

# Opto overcurrent sensing circuit (simulation)

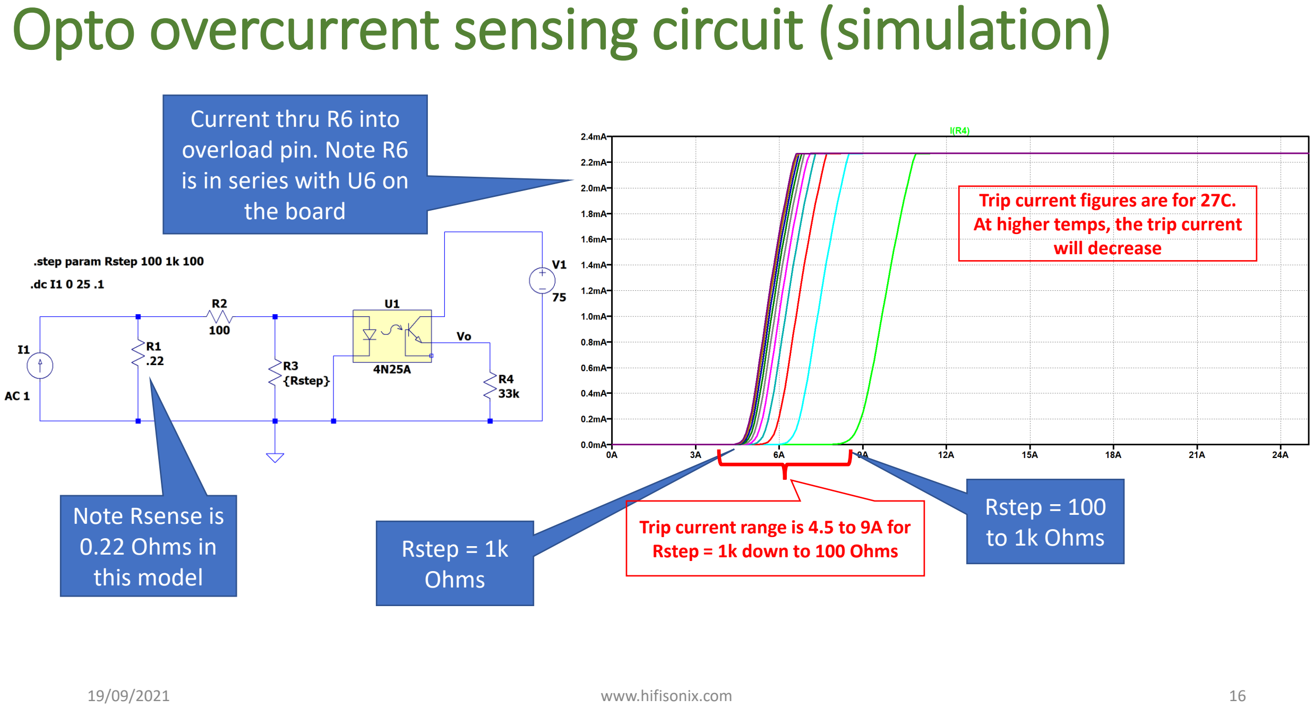
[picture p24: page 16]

Rstep = 100
to 1k Ohms Rstep = 1k
Ohms

Trip current range is 4.5 to 9A for Rstep = 1k down to 100 Ohms

Trip current figures are for 27C. At higher temps, the trip current will decrease

Current thru R6 into
overload pin. Note R6
is in series with U6 on
the board

Note Rsense is
0.22 Ohms in
this model

# Opto overcurrent sensing circuit

## - It is recommended that you only use this circuit for emitter degeneration resistor values of 0.33 Ohms and higher so that sufficient voltage can be developed across the sensing resistors under fault conditions to be able to set the trip current at a reasonably low

level.

## - The slope of the trip activation current (ie the current coming out of the opto emitter pin) is dependent upon the current through the opto emitter diode – the lower it is, the flatter the slope and the wider the

variation in trip current from unit to unit.

# Opto emitter resistor selection

R2 =

vS

RLmin

## × RE − vD

ID

- Where R2 is the resistor in series with the opto emitter diode
- Rlmin is the lowest load impedance the amplifier must drive – below this resistance, the protection circuit must kick in. A good value is 2.8 Ohms
- Re is the emitter degeneration value – for the opto circuit, it is recommended you stay ABOVE 0.22 Ohms
- Vd emitter diode voltage for a current of 5 mA

To prevent ‘false’ tripping, R3 should always be fitted and must be empirically selected. A good option here is to wire a 1k pot in place of R3 and then drive the amplifier into the minimum load impedance at full power. Then adjust the pot so that the amp trips at the correct value – then remove the pot, measure the

resistance and install a resistor of the same measured value into your circuit.

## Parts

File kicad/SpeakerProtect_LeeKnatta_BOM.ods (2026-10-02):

Qty | Value | Footprint | Farnell | Cost
2 | 47uF 16V | D:5 P:2 | 0.114 | 0.228 | 4061537 | Wurth
4 | 1nF | PP W: 4.5 P:5 | 0.203 | 0.812 | 1890180 | Wima FKP2J011001D00JSSD
1 | 100nF 250V | PP W:5 P:5 | 0.373 | 0.373 | 1890267 | Wima MKP2F031001F00KSSD
1 | 470uF 100V | D:16 P7.5 | 1.23 | 1.23 | 4765444 | Nichicon UPW2A471MHD
1 | 330nF | W:4.5 P:5 | 0.146 | 0.146 | 4923530 | Kemet R82EC3330AA70K
1 | 82uF 100V | D:10 P:5 | 0.863 | 0.863 | 860040875004 | Wurth 7000h@105C
 |  |  |  | 0
1 | LED-Red |  |  | 0
1 | LED-Green |  |  | 0
 |  |  |  | 0
9 | BAV21 | Diode_THT:D_DO-35_SOD27_P7.62mm_Horizontal | 0.122 | 1.098 | 4555440
2 | BZX55B18 (18V 0.5W) | Package_DIP:DIP-40_W15.24mm | NA
1 | KBP206G | Diode_THT:Diode_Bridge_14.5x3.5x10.5mm_P3.61 | 0.751 | 0.751 | 3127406
 |  |  |  | 0
4 | 2N5401 | Package_TO_SOT_THT:TO-92_Inline | 0.118 | 0.472 | 4710237 | (Wide)
4 | BC557 | Package_TO_SOT_THT:TO-92_Inline | 0.109 | 0.436 | 4710291 | (Wide)
4 | MJE350 | Package_TO_SOT_THT:TO-126-3_Vertical SOT-32-3 | 0.988 | 3.952 | 9802487
7 | 2N5551 | Package_TO_SOT_THT:TO-92_Inline | 0.131 | 0.917 | 4710238 | (Wide)
3 | BC547 | Package_TO_SOT_THT:TO-92_Inline | 0.102 | 0.306 | 4710269 | (Wide)
3 | MJE340 | Package_TO_SOT_THT:TO-126-3_Vertical SOT-32-3 | 0.65 | 1.95 | 1574367
 |  |  |  | 0
4 | IXFK150N30X3 | Package_TO_SOT_THT:TO-247-3_Vertical |  | 0
 |  |  |  | 0
14 | 100K |  | STOCK
9 | 100R |  | STOCK
1 | 2K |  | STOCK
3 | 47K5 |  | STOCK
2 | 20K |  | STOCK
4 | 0R |  | STOCK
1 | 27R4 |  | STOCK
1 | 10K |  | STOCK
 |  |  |  | 0
2 | 270V | P:7.5 D:14 | 0.498 | 0.996 | 3995499
 |  |  |  | 0
4 | AQY280EH | Package_DIP:DIP-4_W7.62mm | 1.15 | 4.6 | 3588782
2 | ASSR-V621-002E | Package_DIP:DIP-8_W7.62mm | 4.03 | 8.06 | 1708463 | (ASSR-V621-302E – surface mount)
1 | 18V 10W |  | 6.68 | 6.68 | 1689090
0 | 18V 5W |  | 4.75 | 0 | 1689084
1 |  |  |  | 0
7 | ?? |  |  | 0
 |  |  | 23.008 | £33.87

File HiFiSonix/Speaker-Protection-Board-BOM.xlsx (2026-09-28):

Speaker Protection Board BOM
 |  |  |  |  | Sept. 21 2021
www.hifisonix.com
Item | Count | Label-Value | PACKAGE | DESCRIPTION | Designation | Notes/Remarks
1 | 1 | 33uF 16V | RB.2/.1 | MSR 710-860010372003 | C1
2 | 1 | 4.7uF 100V | RB.2/.1 | MSR 80-ESK475M100AC3AA | C2
3 | 1 | .022 50V | RAD0.2 | MSR 594-K223K15X7RF5TL2 | C4
4 | 2 | 680uF 6.3V | RB.2/.4 | MSR 647-UPW0J681MPD | C5,C6
5 | 2 | 1N4007 | DIODE0.4 | MSR 833-1N4007-TP | D1,D2
6 | 1 | 57V 1W | DIODE0.4 | MSR 78-1N4758A | D3 | Only fit D3 if your supply voltage is =>60V
7 | 1 | SPKR ON | LED5 | MSR 859-LTL2R3KEK | D4 | Use any general purpose 5mm diameter RED LED
8 | 1 | Latch | SIP2 | Jumper with wire | J1
9 | 4 | NDMOS | TO220MOSFET | Select Per Application | Q1,Q2,Q3,Q4 | See slide 6 in presentation for some indicative mosfets
10 | 2 | 1.2k | AXIAL0.5 | MSR 293-1.2K-RC | R1,R2 | See table below - must be selected for your specific supply voltage
11 | 4 | 56k | AXIAL0.5 | MSR 293-56K-RC | R3,R6,R8,R9
12 | 1 | 39k | AXIAL0.5 | MSR 293-39K-RC | R4 | See table below - must be selected for your specific supply voltage
13 | 1 | 18k | AXIAL0.5 | MSR 293-18K-RC | R5 | See table below - must be selected for your specific supply voltage
14 | 1 | 1k | AXIAL0.5 | MSR 293-1K-RC | R7
15 | 3 | 12k | AXIAL0.5 | MSR 293-12K-RC | R12,R13
15 | 3 | 12k | AXIAL0.6 | MSR 293-12K-RC | R10 | See table below - must be selected for your specific supply voltage
16 | 1 | 470 1W | AXIAL0.5 | MSR 660-MOS1CT528R471J | R11 | Mount 2-3 mm off the board and secure with RTV
17 | 2 | VOM127 | TLP191 | MSR 78-VOM1271T | U1,U10 | TLP191 can be used as a pin for pin replacement
18 | 1 | Right Out | SPADE | MSR 571-1217861-1-CT | U2
19 | 1 | Left Out | SPADE | MSR 571-1217861-1-CT | U3
20 | 1 | AC Detect | SPADE | MSR 571-1217861-1-CT | U4
21 | 1 | V+ | SPADE | MSR 571-1217861-1-CT | U5
22 | 1 | O/ Current Trip | SPADE | MSR 571-1217861-1-CT | U6
23 | 1 | Left In | SPADE | MSR 571-1217861-1-CT | U7
24 | 1 | UPC1237 | UPC1237 | See Notes | U8 | For UK and EU builders, this device is available from Cricklewood Electronics, London
25 | 1 | Right in | SPADE | MSR 571-1217861-1-CT | U9
26 | 1 | 0V | SPADE | MSR 571-1217861-1-CT | U11
Attention: The resistors in the blue boxes have been selected for supply voltages of => 60V. See table below for other voltages

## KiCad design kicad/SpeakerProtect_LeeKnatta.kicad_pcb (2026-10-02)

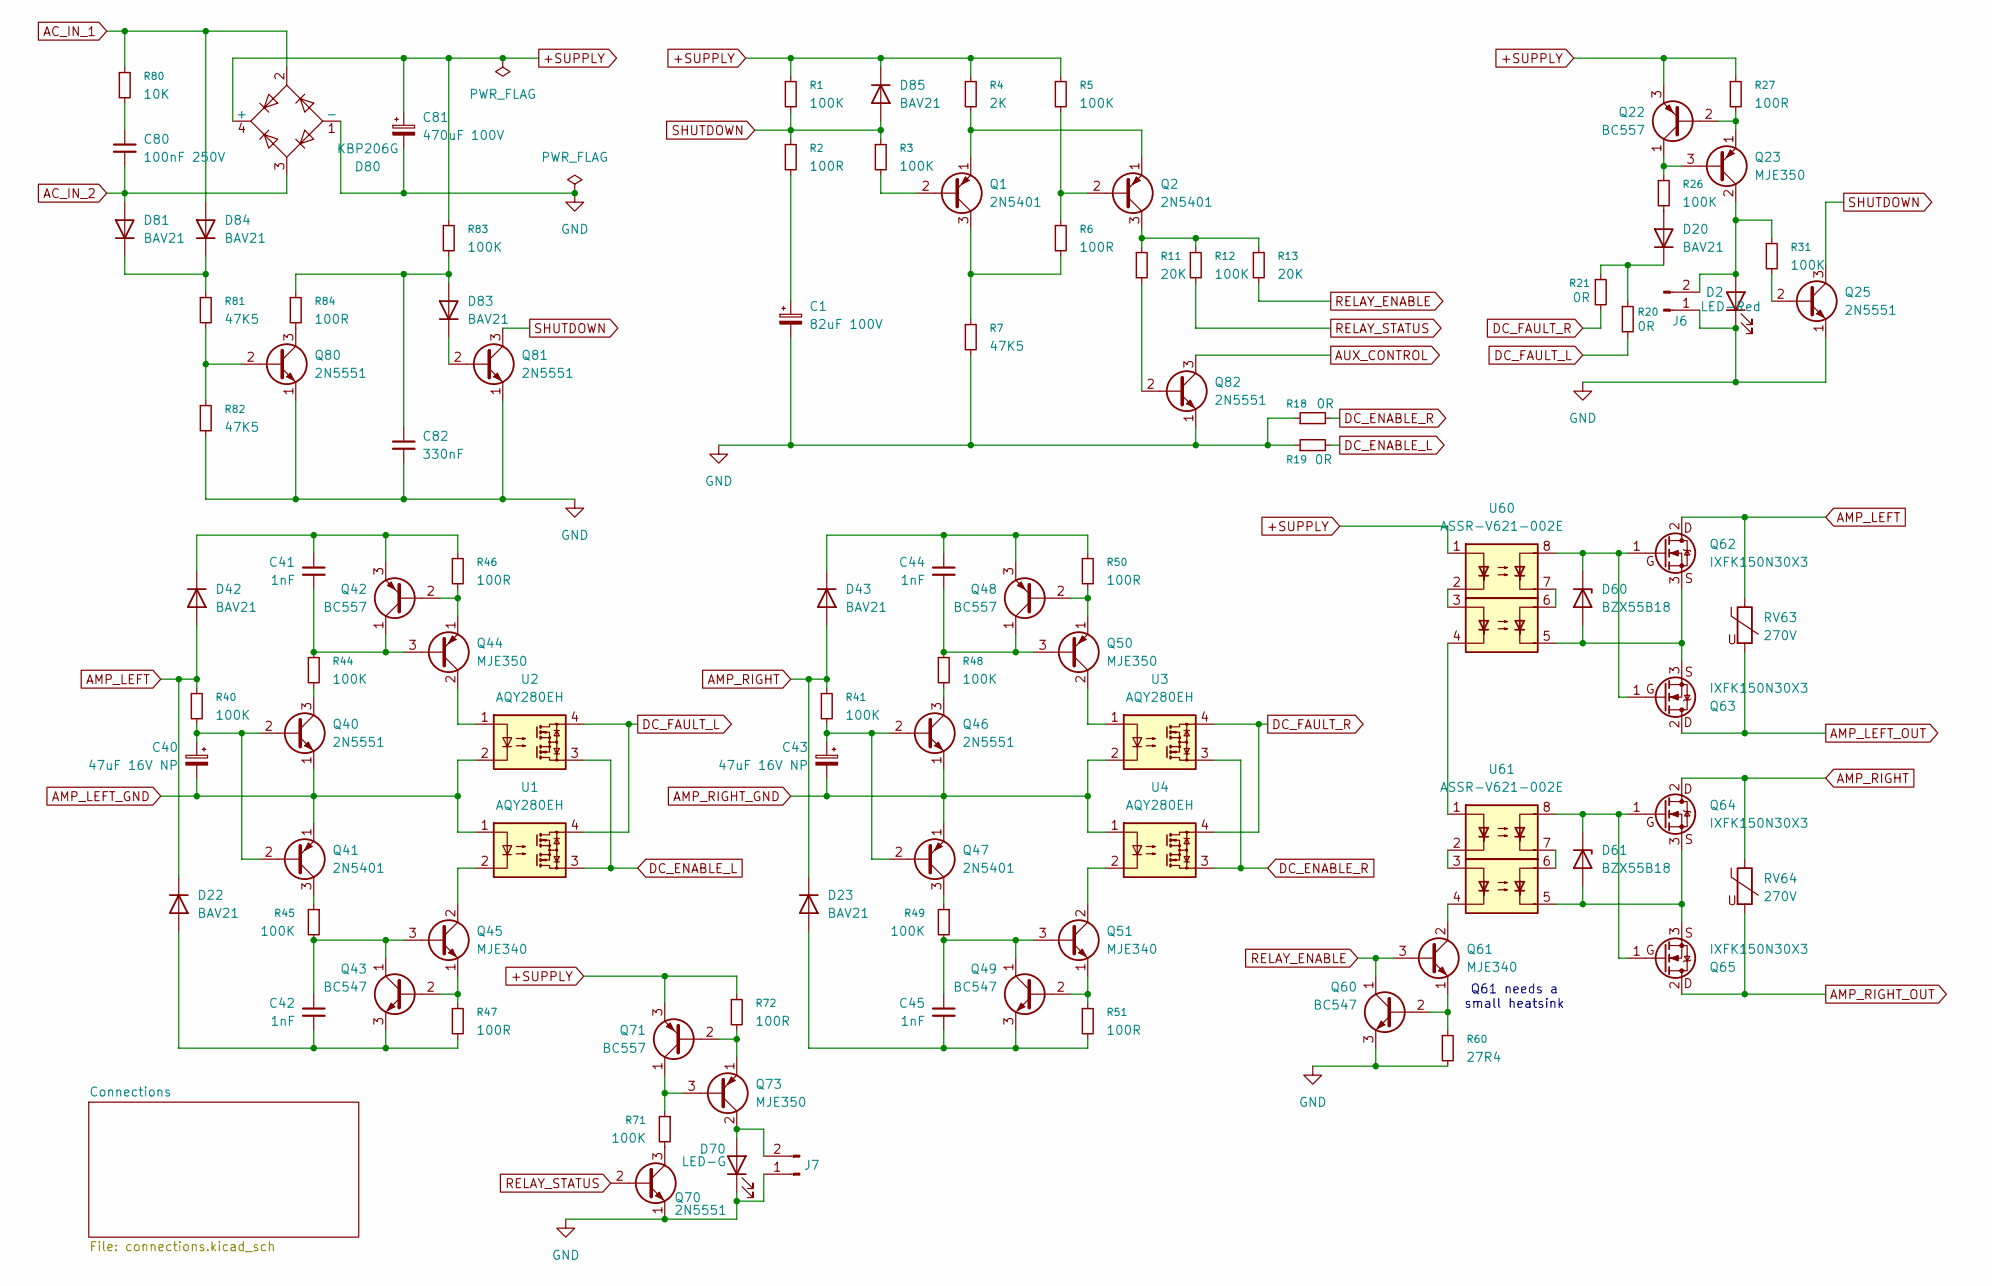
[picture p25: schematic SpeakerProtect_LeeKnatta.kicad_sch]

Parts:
C1: 82uF 100V; CP_Radial_D10.0mm_P5.00mm_P7.50mm
C40, C43: 47uF 16V NP; CP_Radial_D5.0mm_P2.00mm
C41, C42, C44, C45: 1nF; C_Rect_L7.0mm_W4.5mm_P5.00mm
C80: 100nF 250V; C_Rect_L7.2mm_W5.0mm_P5.00mm
C81: 470uF 100V; CP_Radial_D16.0mm_P7.50mm
C82: 330nF; C_Rect_L7.0mm_W4.5mm_P5.00mm
D2: LED-Red
D20, D22, D23, D42, D43, D81, D84, D85: BAV21; D_DO-35_SOD27_P7.62mm_Horizontal
D60, D61: BZX55B18; D_DO-35_SOD27_P7.62mm_Horizontal
D70: LED-G
D80: KBP206G; Diode_Bridge_14.5x3.5x10.5mm_P3.61
D83: BAV21; D_DO-41_SOD81_P2.54mm_Vertical_CathodeUp
J6, J7: Conn_01x02_Pin; TerminalBlock_4Ucon_1x02_P3.50mm_Horizontal
Q1, Q2, Q41, Q47: 2N5401; TO-92_Inline_Wide
Q22, Q42, Q48, Q71: BC557; TO-92_Inline_Wide
Q23, Q44, Q50, Q73: MJE350; TO-126-3_Vertical
Q25, Q40, Q46, Q70, Q80, Q81, Q82: 2N5551; TO-92_Inline_Wide
Q43, Q49, Q60: BC547; TO-92_Inline_Wide
Q45, Q51, Q61: MJE340; TO-126-3_Vertical
Q62, Q63, Q64, Q65: IXFK150N30X3; TO-247-3_Vertical
R1, R3, R5, R12, R26, R31, R40, R41, R44, R45, R48, R49, R71, R83: 100K; R_Axial_DIN0207_L6.3mm_D2.5mm_P10.16mm_Horizontal
R2, R6, R27, R84: 100R; R_Axial_DIN0207_L6.3mm_D2.5mm_P10.16mm_Horizontal
R4: 2K; R_Axial_DIN0207_L6.3mm_D2.5mm_P10.16mm_Horizontal
R7, R82: 47K5; R_Axial_DIN0207_L6.3mm_D2.5mm_P10.16mm_Horizontal
R11, R13: 20K; R_Axial_DIN0207_L6.3mm_D2.5mm_P10.16mm_Horizontal
R18, R19, R20, R21: 0R; R_Axial_DIN0207_L6.3mm_D2.5mm_P10.16mm_Horizontal
R46, R47, R50, R51, R72: 100R; R_Axial_DIN0207_L6.3mm_D2.5mm_P2.54mm_Vertical
R60: 27R4; R_Axial_DIN0207_L6.3mm_D2.5mm_P10.16mm_Horizontal
R80: 10K; R_Axial_DIN0207_L6.3mm_D2.5mm_P10.16mm_Horizontal
R81: 47K5; R_Axial_DIN0207_L6.3mm_D2.5mm_P2.54mm_Vertical
RV63, RV64: 270V; RV_Disc_D15.5mm_W7.5mm_P7.5mm
U1, U2, U3, U4: AQY280EH; DIP-4_W7.62mm
U60, U61: ASSR-V621-002E; DIP-8_W7.62mm

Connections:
+SUPPLY: C81.1, D80.4 (+), D85.1 (K), Q22.3 (E), Q71.3 (E), R1.1, R4.1, R5.1, R27.1, R72.1, R83.1, U60.1
AC_IN_1: D80.2, D84.2 (A), R80.1; also elsewhere on the board
AC_IN_2: C80.2, D80.3, D81.2 (A); also elsewhere on the board
AMP_LEFT: D22.1 (K), D42.2 (A), Q62.2 (D), R40.1, RV63.1; also elsewhere on the board
AMP_LEFT_GND: C40.2, Q40.1 (E), Q41.1 (E), U1.1, U2.2; also elsewhere on the board
AMP_LEFT_OUT: Q63.2 (D), RV63.2; also elsewhere on the board
AMP_RIGHT: D23.1 (K), D43.2 (A), Q64.2 (D), R41.1, RV64.1; also elsewhere on the board
AMP_RIGHT_GND: C43.2, Q46.1 (E), Q47.1 (E), U3.2, U4.1; also elsewhere on the board
AMP_RIGHT_OUT: Q65.2 (D), RV64.2; also elsewhere on the board
AUX_CONTROL: Q82.3 (C)
DC_ENABLE_L: R19.2, U1.3, U2.3
DC_ENABLE_R: R18.2, U3.3, U4.3
DC_FAULT_L: R20.2, U1.4, U2.4
DC_FAULT_R: R21.2, U3.4, U4.4
GND: C1.2, C81.2, C82.2, D2.1 (K), D70.1 (K), D80.1 (-), J6.1, J7.1, Q25.1 (E), Q60.3 (E), Q70.1 (E), Q80.1 (E), Q81.1 (E), Q82.1 (E), R7.2, R18.1, R19.1, R60.2, R82.2
unnamed: C1.1, R2.2
unnamed: C80.1, R80.2
unnamed: D20.2 (A), R26.2
unnamed: D20.1 (K), R20.1, R21.1
unnamed: C42.2, D22.2 (A), Q43.3 (E), R47.2
unnamed: C45.2, D23.2 (A), Q49.3 (E), R51.2
unnamed: C41.1, D42.1 (K), Q42.3 (E), R46.1
unnamed: C44.1, D43.1 (K), Q48.3 (E), R50.1
unnamed: D60.2 (A), Q62.3 (S), Q63.3 (S), U60.5
unnamed: D60.1 (K), Q62.1 (G), Q63.1 (G), U60.8
unnamed: D61.2 (A), Q64.3 (S), Q65.3 (S), U61.5
unnamed: D61.1 (K), Q64.1 (G), Q65.1 (G), U61.8
unnamed: D81.1 (K), D84.1 (K), R81.1
unnamed: C82.1, D83.2 (A), R83.2, R84.1
unnamed: D83.1 (K), Q81.2 (B)
unnamed: D2.2 (A), J6.2, Q23.2 (C), R31.1
unnamed: D70.2 (A), J7.2, Q73.2 (C)
unnamed: Q1.2 (B), R3.2
unnamed: Q1.3 (C), R6.2, R7.1
unnamed: Q1.1 (E), Q2.1 (E), R4.2
unnamed: Q2.2 (B), R5.2, R6.1
unnamed: Q2.3 (C), R11.1, R12.1, R13.1
unnamed: Q22.2 (B), Q23.1 (E), R27.2
unnamed: Q22.1 (C), Q23.3 (B), R26.1
unnamed: Q25.2 (B), R31.2
unnamed: C40.1, Q40.2 (B), Q41.2 (B), R40.2
unnamed: Q40.3 (C), R44.2
unnamed: Q41.3 (C), R45.1
unnamed: Q42.2 (B), Q44.1 (E), R46.2
unnamed: C41.2, Q42.1 (C), Q44.3 (B), R44.1
unnamed: Q43.2 (B), Q45.1 (E), R47.1
unnamed: C42.1, Q43.1 (C), Q45.3 (B), R45.2
unnamed: Q44.2 (C), U2.1
unnamed: Q45.2 (C), U1.2
unnamed: C43.1, Q46.2 (B), Q47.2 (B), R41.2
unnamed: Q46.3 (C), R48.2
unnamed: Q47.3 (C), R49.1
unnamed: Q48.2 (B), Q50.1 (E), R50.2
unnamed: C44.2, Q48.1 (C), Q50.3 (B), R48.1
unnamed: Q49.2 (B), Q51.1 (E), R51.1
unnamed: C45.1, Q49.1 (C), Q51.3 (B), R49.2
unnamed: Q50.2 (C), U3.1
unnamed: Q51.2 (C), U4.2
unnamed: Q60.2 (B), Q61.1 (E), R60.1
unnamed: Q61.2 (C), U61.4
unnamed: Q70.3 (C), R71.2
unnamed: Q71.2 (B), Q73.1 (E), R72.2
unnamed: Q71.1 (C), Q73.3 (B), R71.1
unnamed: Q80.2 (B), R81.2, R82.1
unnamed: Q80.3 (C), R84.2
unnamed: Q82.2 (B), R11.2
unnamed: U60.2, U60.3
unnamed: U60.4, U61.1
unnamed: U60.6, U60.7
unnamed: U61.2, U61.3
unnamed: U61.6, U61.7
RELAY_ENABLE: Q60.1 (C), Q61.3 (B), R13.2
RELAY_STATUS: Q70.2 (B), R12.2
SHUTDOWN: D85.2 (A), Q25.3 (C), Q81.3 (C), R1.2, R2.1, R3.1

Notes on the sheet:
Q61 needs a small heatsink

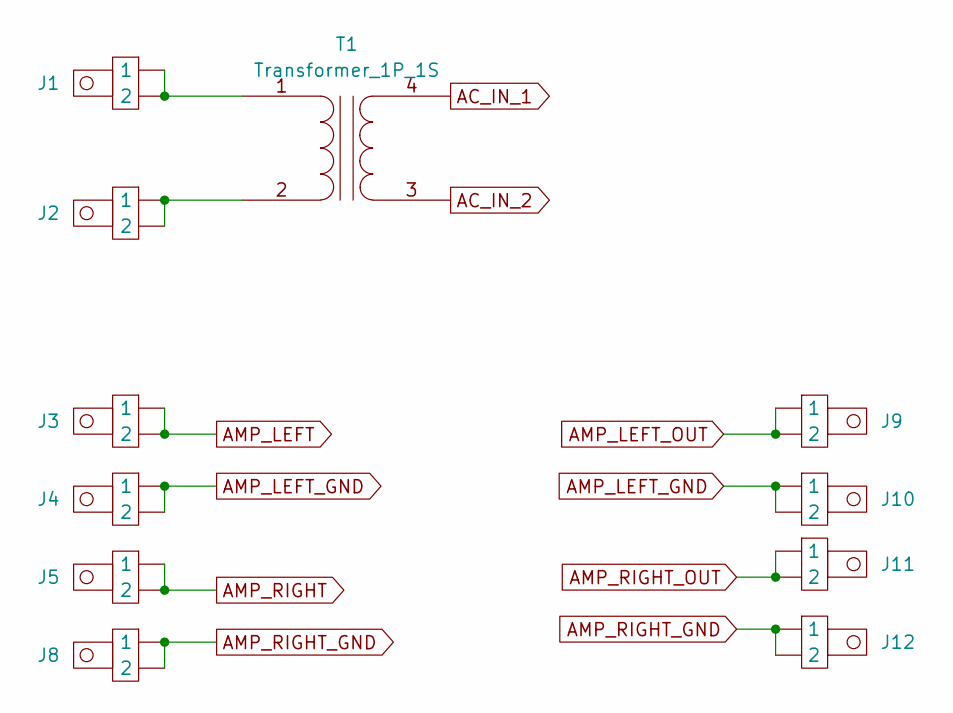
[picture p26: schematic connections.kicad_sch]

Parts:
J1, J2, J3, J4, J5, J8, J9, J10, J11, J12: Spade_Connector
T1: Transformer_1P_1S; Transformer_Myrra-44233-230V-18V-5VA-37x44

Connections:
AC_IN_1: T1.4 (SB); also elsewhere on the board
AC_IN_2: T1.3 (SA); also elsewhere on the board
AMP_LEFT: J3.1, J3.2; also elsewhere on the board
AMP_LEFT_GND: J4.1, J4.2, J10.1, J10.2; also elsewhere on the board
AMP_LEFT_OUT: J9.1, J9.2; also elsewhere on the board
AMP_RIGHT: J5.1, J5.2; also elsewhere on the board
AMP_RIGHT_GND: J8.1, J8.2, J12.1, J12.2; also elsewhere on the board
AMP_RIGHT_OUT: J11.1, J11.2; also elsewhere on the board
unnamed: J1.1, J1.2, T1.1 (AA)
unnamed: J2.1, J2.2, T1.2 (AB)

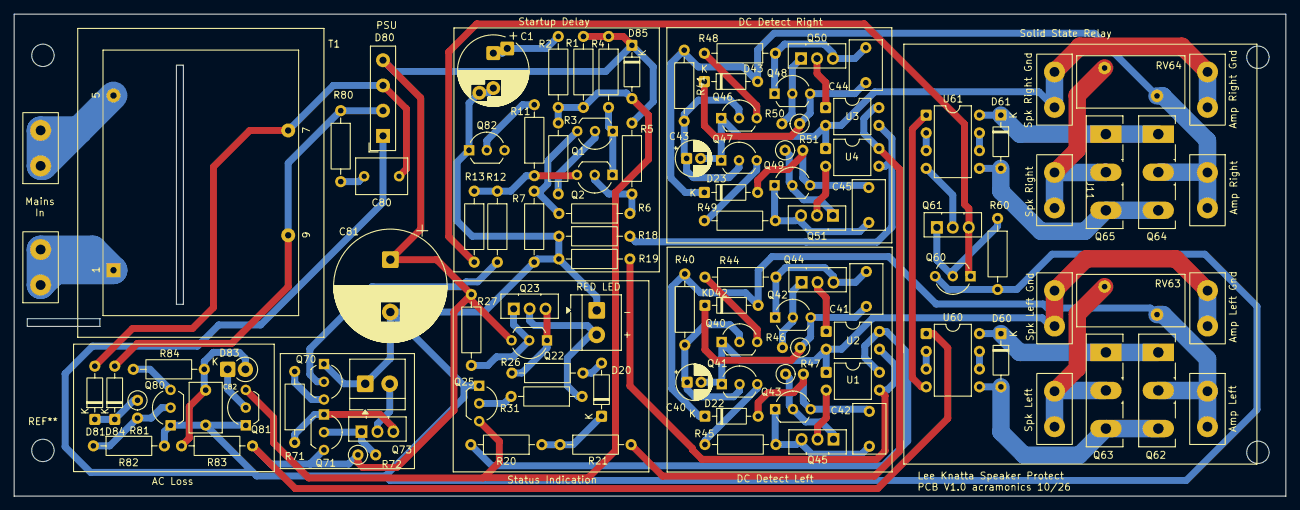
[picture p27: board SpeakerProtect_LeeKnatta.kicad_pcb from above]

Board: 2 copper layers, 182.0 x 69.0 mm, 107 parts (0 on the bottom side), 75 nets.

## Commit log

2026-09-26 Added kicad directory
    [SpeakerProtect_LeeKnatta.kicad_pcb, SpeakerProtect_LeeKnatta.kicad_sch]
2026-09-27 Added more schematics
    [SpeakerProtect_LeeKnatta.kicad_sch]
2026-09-28 Added HiFiSonix design
    [Speaker-Protection-Board-BOM.xlsx, SpeakerProtect_LeeKnatta.kicad_sch]
2026-10-01 Added connections and started PCB
    [SpeakerProtect_LeeKnatta.kicad_pcb, SpeakerProtect_LeeKnatta.kicad_sch, connections.kicad_sch]
2026-10-02 Completed PCB
    [SpeakerProtect_LeeKnatta.kicad_pcb, SpeakerProtect_LeeKnatta.kicad_sch, SpeakerProtect_LeeKnatta_BOM.ods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]
